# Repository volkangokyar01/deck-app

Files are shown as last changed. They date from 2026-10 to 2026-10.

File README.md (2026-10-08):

## Firmware derleme

```sh
tools/build_firmware.sh      # arduino-cli compile → firmware/bin → embed_firmware.py → build.py
```

Gerekenler: arduino-cli, esp32:esp32 3.3.12, LovyanGFX 1.2.x, ArduinoJson 7.4, NimBLE-Arduino 2.5.1. Betik Arduino'ya `BOARD_HAS_PSRAM` verir (yoksa Arduino 3.x kendi PSRAM katmanını derlemez, 8 MB ek bellek kullanılmaz) ve Arduino çekirdeğinin önbelleğini bu bayraklara göre ayırır (`firmware/VolkanDeck/build/cache-…`). Betik NimBLE'ye `MYNEWT_VAL_BLE_STORE_MAX_CCCDS=32` ve `MYNEWT_VAL_BLE_STORE_MAX_BONDS=4` verir; bunlar olmadan derleme bilerek hata verir (ayrıntı: `docs/kararlar-ve-pinler.md`, 2026-10-08). `arduino-cli` başka yerdeyse `ARDUINO_CLI=/yol/arduino-cli`, ayar dosyası için `ARDUINO_CONFIG=/yol/cli.yaml`.

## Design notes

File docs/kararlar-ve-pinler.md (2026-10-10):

# Volkan Deck — kararlar ve pinler

## Donanım
- LilyGO T-Display-S3 (ESP32-S3R8, 16MB Flash / 8MB OPI PSRAM, 1.9" 320x170 ST7789 8-bit paralel, dokunmatik DEĞİL)
- KY-040 döndürgeç, 2 × MX switch + 1u tuş kapağı (A/B; henüz alınmadı), Efcell 2000 mAh 3.7V Li-Po, 2 pin JST 1.25 mm uzatma kablosu
- Kartın arkasına pin başlıkları lehimli (Dupont ile bağlanıyor)

## Kullanım modeli: uygulama başlatıcı
- Döndürgeç listesi: [Ana sayfa] + uygulamalar. Sağa/sola: gezinir; basma: seçili uygulamayı açar (ana sayfada isteğe bağlı uygulama); uzun basma (0,7 sn): ana sayfaya dön
- A ve B butonları: atanan uygulamayı doğrudan açar (hızlı açma)
- Kartın kendi tuşları (v1.1.1'den itibaren yer değiştirdi): GPIO 0 (BOOT) = güç (kısa: ekran kapat/aç, 2 sn: derin uyku, tekrar basınca uyanır), GPIO 14 = reset (bırakınca ESP.restart; yalnız firmware çalışırken, yükleme modunda etkisiz)
- Kapanma (2026-10-05): yazılımsal güç kesici yok; kapalı durum derin uykudur, USB takılıyken kart hâlâ güç çeker. GPIO0 RTC pull-up açık / pull-down kapalı, RTC çevre birimi açık; tuş kesintisiz 80 ms bırakılmadan EXT0 (LOW) kurulmaz. Arka ışık GPIO38 ve LCD güç GPIO15 LOW tutulur; diğer uyandırma kaynakları temizlenir, BLE durdurulur, USB bağlantısı kesilir
- Kapalı durum RTC_NOINIT_ATTR içindeki 32 bit işaretle korunur: setup'ın ilk kontrolü, işaret varken POWERON ve EXT0 dışındaki reset/uyanışlarda ekranı açmadan sessizce yeniden uyutur (USB-Serial-JTAG DTR/RTS, watchdog, RTC belleği korunmuş brownout dahil). Gerçek EXT0 veya POWERON işareti temizler; GPIO0/LCD RTC hold ve RTC yapılandırması, arka ışık hold normal açılışta bırakılır. CDCOnBoot nedeniyle Arduino çekirdeği USB'yi setup'tan önce başlatır; sessiz yolda hemen bağlantısı kesilir, firmware HID/seri başlatmasına ulaşılmaz. ROM yükleme modu veya RTC belleğini kaybettiren güç düşüşü yazılımla engellenemez
- Donanım doğrulaması bekliyor: pil/USB'de uzun basma → kapalı kalma → tekrar tuşla uyanma, masaüstünün 3 sn bağlantı denemeleri, DTR/RTS resetleri, watchdog/brownout sonrası RTC işareti ve ekran/arka ışık seviyeleri; kapalı akımı ölçülmeli
- Boşta kalınca ana sayfaya dönüş (varsayılan 60 sn). Karartma ve otomatik kapanma kabloda ve pilde ayrı (v1.5.1): device.dimAfterUsb / sleepAfterUsb (varsayılan 30 sn / kapalı), device.dimAfter / sleepAfter (pilde, varsayılan 30 sn / 5 dk); 0 = kapalı. Kablo = USB'ye bağlı ya da şarj oluyor
- Ekran teması (2026-10-05): device.theme = auto (varsayılan) / dark / light. Koyu: saf siyah zemin, nötr griler; açık: kırık beyaz kasaya uygun sıcak beyaz. device.lightFrom = 420 (07:00), device.darkFrom = 1140 (19:00), yerel gece yarısından sonraki dakika; 0..1439 ile sınırlı. Eski config bu varsayılanları alır.
- Otomatik tema: açık başlangıcı dahil, koyu başlangıcı hariç; açık başlangıcı daha geçse gece yarısını aşan aralık, başlangıçlar aynıysa tüm gün koyu. Saat masaüstünün `stats.time` (epoch + tz) verisinden, arada millis ile ilerler; ilk saat gelene kadar koyu. Açılışta ve ayar değişince uygulanır, döngüde 3 sn’de bir denetlenir; değişince tam ekran çizilir (kapatma/reset yazıları da aynı palet).
- Ekran 180° çevirme: Cihaz ayarları → "Ekranı 180° çevir" (device.flip)

## Medya ve Ses/parlaklık sayfaları (v1.3.0, 2026-10-05)
- 2026-10-06 (v1.5.3): Döndürgeç ve A/B ile Spotify, Apple Music veya YouTube Music açılınca etkin Medya sayfasına geçilir; oynatıcı yalnız oturum için sabitlenir, pages.media.player değişmez. Ad ve launch.value/path/mac üzerinde büyük-küçük harf duyarsız tanıma cihazda yapılır. pages.media.launch (none / spotify / music / ytmusic, eski ayarda none) çalan uygulama yokken masaüstü uygulamasının açacağı oynatıcıdır; oturum sabiti önce gelir. Oynatıcı yokken açma seçilmişse masaüstü ctl:app bildirir; yeni masaüstü companion.mediaLaunch:true yeteneğini bildirir, böylece ilk durum yanıtından önce de sabit oynatıcıya oynat iletilir; eski masaüstünde eksik yetenek false sayılır. Mevcut evt media ve HID yolu korunur, masaüstü yokken kararı işletim sistemi verir.
- Döndürgeç listesi: [Ana sayfa] [Medya] [Ses ve parlaklık] + uygulamalar (pages.media.enabled / pages.system.enabled)
- Medya: oynatıcı çipleri (Spotify / Apple Music / YouTube Music), şarkı, sanatçı, süre çubuğu, ses. Bas: oynat/duraklat · A: önceki · B: sonraki · basılı tut: ses modu (çevir: ses, 6 sn sonra çıkar) · çift bas: oynatıcı değiştir (oto → Spotify → Apple Music → YouTube Music). Varsayılan: pages.media.player
- Medya sayfasında kalma: pages.media.stay (bool, varsayılan true; eski config'te eksikse de true). Medya ayarındaki "Medya sayfasındayken ana sayfaya dönme" açıkken yalnız Medya sayfasında home.returnAfter atlanır; karartma ve pilde otomatik kapanma aynen devam eder. Kapatılırsa normal ana sayfaya dönüş süresi uygulanır
- Ses ve parlaklık: iki satır. Bas: ayar modu ses ↔ parlaklık · çevir: değer (ses %2, parlaklık %5) · basılı tut: çık · A: sessiz · B: satır değiştir
- Masaüstü uygulaması yoksa cihaz HID tüketici tuşları gönderir (oynat/duraklat, ileri, geri, ses ±, sessiz, parlaklık ±); BLE rapor haritasına rapor 2 eklendi (Bluetooth'ta yeniden eşleştirme gerekebilir)
- Windows: win-helper.ps1 sürekli açık (SMTC medya oturumları, Core Audio, WMI + DDC/CI parlaklık; parlaklık 10 sn'de bir okunur). Tarayıcı oturumları YouTube Music sayılır
- macOS: AppleScript (Spotify, Music; Chrome/Edge/Brave/Safari'de music.youtube.com sekme adı; ses), parlaklık JXA + DisplayServices (MacBook Air'de denendi, çalışıyor). YouTube Music kontrolü medya tuşuyla
- Ekran fontlarında yalnız ASCII + Türkçe harfler var; şarkı adları uygulamada sadeleştirilir (é → e)
- Albüm kapağı (v1.3.2): macOS'te Spotify artwork URL, Music yerel artwork verisi; yoksa iTunes Search API. Windows'ta seçili Spotify/Apple Music SMTC oturumunun thumbnail'ı. Parça değişince arka planda alınır, 64×64 RGB565 olarak USB'den gönderilir; tarayıcı/YouTube Music için kapak yok

## Ana sayfa
- Sol: 128x128 animasyon alanı (hazır: fan [CPU sıcaklığıyla hızlanır], radar, nabız, ekolayzer; veya kullanıcı GIF'i → RGB565 kareler, en fazla 60, /anim.bin)
- GIF kalıcı (v1.2.1): yükleme doğrudan flash'a yazılır (/anim.tmp → /anim.bin), config'e home.anim.kind="custom" kaydedilir; açılışta PSRAM'e, olmazsa RAM'e (≤96 KB) yüklenir, o da olmazsa kareler flash'tan akıtılır
- GIF'in kendi kare süreleri (v1.3.1): kare süreleri eşit değilse (ör. hareketler arasında uzun bekleme) ayar sayfası `anim_begin` içinde `delays` (ms, kare başına) gönderir; /anim.bin başlığında bayrak bit0 = süre tablosu var (başlıktan sonra n × uint16). Süre tablosu yoksa sabit kare/sn kullanılır. Süre tablosu varken `fps` yalnız tasarruf hızını sınırlar (`ecoAnimFps = min(animFps, ecoFps)`); 2026-10-06'dan beri ayar sayfası onu ortalamadan değil en kısa kareden hesaplar, yoksa uzun beklemeler ortalamayı ~1 kare/sn'ye düşürüp tasarrufta animasyonu donduruyordu. GIF 60 kareden uzunsa kare atlanır ve süre tablosu gönderilmez
- Animasyonun altı: A/B tuşlarına atanmış uygulamaların ikonu + adı (v1.3.0'da harf yerine ikon; yeni yerleşimde üst üste iki satır olduğu için A/B harfi de yeniden gösteriliyor)
- Sağ: iki kart yuvası (v1.4.0, home.cards, varsayılan cpu + gpu; 186×76 / 186×75). Her yuvaya ayar sayfasında biri seçilir; veriyi masaüstü uygulaması USB'den `stats` ile gönderir. Cihaz Wi-Fi kullanmaz
  - CPU / GPU: büyük °C, ad (home.cpuLabel/gpuLabel boşsa bilgisayardan gelen ad), başlıkta güç W ve yük %, ikinci satırın sağında GPU fan % + VRAM (5,2/12 GB) / CPU GHz, son 40 sıcaklığın çizgisi, 0–110 °C çubuk; sarı/kırmızı eşikler (CPU 85/95, GPU 80/87). Sıcaklık gelmezse (sürücü yok, Intel Mac) büyük rakam yük % olur, sağda "sıcaklık okunamıyor"
  - Saat: ortada büyük SS:DD (24 saat), altında Türkçe tarih ("Pzt 5 Eki"); `time` (epoch + tz) gelir, arada millis ile ilerler
  - Hava durumu: şehir, durum adı, WMO kodundan vektör ikon (açık, parçalı bulutlu, bulutlu, sis, yağmur/çisenti, kar, gök gürültüsü; yalnız gündüz), büyük °, sağda en yüksek / en düşük (▲/▼), başlıkta yağış %. Şehir ayar sayfasında Open-Meteo şehir aramasıyla seçilir (home.weather {city, lat, lon}, varsayılan İstanbul); cihaz city'yi yalnız veri gelmeden önce etiket olarak kullanır
  - Döviz: USD ve EUR iki satır, TL karşılığı 2 ondalık (virgüllü), sağda önceki güne göre % değişim (yeşil ▲ / kırmızı ▼, değişim yoksa gri)
  - Ağ: büyük indirme hızı (Mb/s; 1 Mbit/s altında kB/s, 1000 üstünde Gb/s), altta yükleme, başlıkta ping (yeşil < 40 ms, sarı < 100, kırmızı), indirme çizgisi (0 tabanlı)
  - Eskime: cpu/gpu/net 5 sn, hava/döviz 2 saat; eski veya null alan "-" gösterir (uydurma değer yok). Uygulama kapalıysa kartta "Masaüstü uygulaması kapalı", açıksa "Veri bekleniyor…"
- Eski sıcaklık yolu v1.4.0'da kaldırıldı: cihazın Wi-Fi ile LibreHardwareMonitor data.json okuması (Sensors.h), sensors.* ayarları, sensor_test / temps komutları ve temps olayı. Eski config'teki sensors nesnesi yok sayılır; get_config yanıtından ve set_config kaydından silinir (Wi-Fi şifresi dahil)
- Ana sayfa veri kaynağı: masaüstü `app/stats.js` → USB `stats` (firmware ≥1.4.0). Windows NVIDIA GPU: sürücüyle gelen `nvidia-smi` sürekli CSV akışı; AMD/Intel GPU desteği henüz yok. CPU yükü `os.cpus()` farkları; desteklenmeyen alanlar `null`.

## Ekran yerleşimi (2026-10-05, "her pikseli kullan")
- Kural: dış kenar 2 px, paneller arası 2 px; paneller çizgiyle değil zemin tonuyla ayrılır (koyu SC_PANEL #0F1012 / SC_BG #000000; açık #ECE8E0 / #FAF8F3). Seçili/odaklı alan çerçeve yerine renk tonuyla gösterilir (amber karışımı)
- Üst renkli 3 px çizgi kaldırıldı; sayfa rengi artık sayfa sayacının önündeki 8 px noktada. Durum satırı y 0..13 (eskiden 0..23), içerik y 15..167
- Ana sayfa: animasyon 128×128 sol üst köşede (2,2), köşe yarıçapı 8 aynı; durum satırı animasyonun sağında (sayaç x 134). A/B satırları animasyonun altında üst üste (A üstte; harf + ikon + ad, 128×17). CPU/GPU kartları 186×76/75 (eskiden 174×62); sıcaklık 36 px
- Uygulama sayfası: ikon r 33 (eskiden 31), yan ikonlar r 21, ad tam genişlikte; A/B yuvaları 157×26, alt kenara yaslı
- Medya: çipler y 16, kapak 64×64 (2,37), başlık/sanatçı/süre çubuğu yanında; sabitlenen oynatıcı çipi çerçeve yerine kendi renginde soluk dolgu; ses kendi panelinde (86×62), % 18 px kalın; ses modunda panel amber tonlu
- Ses ve parlaklık: iki satır 316×76/75, değer 36 px, çubuk 8 px; odaklı satır amber tonlu (çerçeve yok)
- Bildirim (toast): çerçeveli siyah kutu yerine dolu amber hap, alt kenarda (y 142..167)
- 36 px font: Fonts.h `fN36`, Inter SemiBold, yalnız " %+,-./0-9:" (8,6 KB; v1.4.0'da saat ve ondalıklar için ":,." eklendi, eski glifler aynı); üretimde mevcut fontların VLW kuralları (asc = boy, glif genişliği = ilerleme) kullanıldı. Diğer yazılarda en küçük boy yine 9 px
- Simülatör (web/body.html) aynı koordinatları ve koyu/açık paletleri kullanır; otomatik tema tarayıcının yerel saatine göre 3 sn’de bir denetlenir. Cihaz ayarları → Ekran teması; otomatik seçilince iki HH:MM başlangıç alanı açılır. Sayfa/marka, oynatıcı ve kullanıcı uygulama renkleri sabit; dolgularda kontrasta göre beyaz/koyu yazı, soluk renklerde mevcut zemin/panel ile karışım. Hazır Icons.h ikonları alfa maskesi; albüm kapağı, uygulama ikon görselleri ve kullanıcı GIF kareleri değiştirilmez

## Uygulama ekleme
- "Bilgisayardan seç…" veya sürükle-bırak: .exe (PE'den ikon + ad), .lnk, .url
- Masaüstü uygulamasında dosya yolu da kaydedilir (app.targets.win); macOS'te .app seçilir veya Finder'dan sürüklenir (app.targets.mac)
- Uygulama başına "Arka planda aç" (app.bg): Windows start /MIN, macOS open -g

## Uygulama açma (karar 2026-10-05)
- Kullanıcı Windows arama veya Çalıştır (Win+R) kullanılmasını istemiyor: uygulamalar yalnızca masaüstü uygulaması tarafından sistem çağrısıyla açılır
- Masaüstü uygulaması kapalıyken cihaz yazmaz, "Volkan Deck uygulaması açık değil" gösterir; klavye yedeği (Win+R / Başlat / Spotlight) yalnızca device.kbFallback açılırsa (varsayılan kapalı)
- Görev çubuğu (Win+1..9) ve kısayol tuşu yöntemleri klavyeyle gönderilmeye devam eder
- Yöntem adları masaüstünde: "Dosya, adres veya komut" (run) ve "Uygulama adı" (search → Başlat menüsü kaydı, arama UI'si yok)

## Masaüstü uygulaması (Windows + macOS) — 2026-10-05
- Electron 44.5.1, tek kod tabanı; ayar sayfası pencere içinde (Web Serial; ana süreç VID 0x303A portunu kendisi seçer, 3 sn'de bir otomatik bağlanır)
- Cihaz → {"evt":"launch","app","name","method","value","path","mac"}; uygulama yerel ayardan targets/bg'yi tamamlar
- Windows: .exe → CreateProcess (cwd = klasörü); .lnk/.url → ShellExecute (openPath); adres → openExternal; komut → doğrudan exe ya da cmd start (App Paths); ad → Get-StartApps + shell:AppsFolder; bg → start /MIN
- macOS: open / open -a / mdfind; bg → open -g
- Kalp atışı {"cmd":"companion","os":"win|mac"} 2 sn'de bir; firmware 6 sn içinde aldıysa ve port açıksa (DTR) doğrudan açar
- Windows CPU sıcaklık/güç: PawnIO **2.2.0** + LibreHardwareMonitorLib **0.9.6** (.NET Framework paketi, MPL-2.0); eski web sunucusu kurulumu yok. LHM 0.9.5’te PawnIO’ya geçti. PawnIO sürücü DACL’si SYSTEM/yönetici erişimi gerektirdiği için uygulamada tek seferlik “CPU sıcaklığı için sürücüyü kur” adımı vardır. SHA-256 + Authenticode doğrulamasından sonra aynı UAC içinde SYSTEM sensör görevi oturum açılışına kaydedilir; Electron normal kullanıcı olarak kalır.
- Sensör görevi `%ProgramFiles%\VolkanDeckSensors\<SID>` içindeki yöneticiye ait salt okunur kod/DLL’lerle CPU paket sensörünü okur; `%ProgramData%\VolkanDeckSensors\<SID>\readings.json` kullanıcıya yalnız okuma izniyle sunulur. Ağ dinleyicisi/komut kanalı yok; beş saniyeden eski ya da hatalı değer `null`. Görev uygulama kapalıyken de çalışır; kaldırmak için yönetici PowerShell’de `Get-ScheduledTask 'VolkanDeckSensors-*' | Unregister-ScheduledTask -Confirm:$false`, ardından korumalı sensör klasörlerini silin. PawnIO ayrı olarak Windows uygulama listesinden kaldırılabilir.
- Apple Silicon macOS: MIT lisanslı **macmon 0.8.2**, `macmon pipe -i 1000` JSON akışı (sudo yok), CPU/GPU sıcaklık/yük/güç ve GHz; GPU adı Apple çip adı. İndirme arşivi SHA-256 ile sabitlenir, ikili ad-hoc imzalanıp `codesign --verify --strict` ile doğrulanır. Intel Mac veya sensör hatasında `os.cpus()` yükü, sıcaklıklar `null`.
- Ağ: aktif loopback dışı arayüzlerin byte farkları → Mbit/s; Mac `netstat -ibn`, Windows ayrı küçük PowerShell/.NET yardımcısı. Ping her 5 sn’de 1.1.1.1:443 TCP bağlantı süresi (yedek 8.8.8.8).
- Hava: [Open-Meteo](https://open-meteo.com/en/docs) güncel °C/WMO kodu ve bugünün max/min/yağış olasılığı, `home.weather.lat/lon` seçilince, 15 dk önbellek. Kur: [Frankfurter v2](https://frankfurter.dev/) ECB verisi, USD/TRY + EUR/TRY ve önceki yayımlanan iş gününe göre %, 30 dk önbellek. Anahtar gerekmez; Electron `net.fetch`, 10 sn timeout, hatada son iyi veri (2 saate kadar).
- İkili/DLL dosyaları ilk kullanımda kullanıcı veri klasörüne sabit SHA-256 ile indirilir; repo ve GitHub `app/` güncellemesi küçük kalır. Kaynaklar, hash’ler, bağımlılıklar ve doğrulama notları: `app/vendor/README.md`. CPU/GPU/net yaklaşık 1 sn, saat bağlantıda + 60 sn; yavaş gruplar ayrıca ilk yanıt geldiğinde gönderilir. Medya/sys/kapak akışından bağımsızdır.
- Çarpıya basınca kapanmaz, arka planda çalışır: Windows'ta sistem tepsisi simgesi (+ görev çubuğu durumu), macOS'te yalnız menü çubuğu simgesi (Dock'ta görünmez; accessory modu). Simge bağlantı durumunu gösterir (dolu / yarım / boş)
- İlk açılışta "bilgisayar açılınca başlat" açık
- Dağıtım: VolkanDeck-kurulum.zip (Windows-Kur.bat / Mac-Kur.command Electron'u GitHub'dan indirip kurar). Mac'te /Applications/Volkan Deck.app kurulu; güncellemeler Contents/Resources/app'e yazılıyor
- macOS 27'de app.getFileIcon ana süreçte çöküyordu; ikon artık plutil + sips ile .icns'ten okunuyor
- Kaynak: GitHub volkangokyar01/deck-app (app/main.js, preload.js, companion.js — ayar sayfasının IIFE'sine gömülür, tools/build.py)
- Sınır: doğrudan açma USB'de; v1.6.0'dan itibaren kablo bu bilgisayara takılı değilse Bluetooth veri kanalıyla da (aşağıda)

## Bluetooth veri kanalı (v1.6.0, 2026-10-06)
- Önceden Bluetooth yalnız HID klavye + medya tuşuydu; ayarlar, stats, medya ve launch olayları yalnız USB seri porttan gidiyordu
- Yeni GATT servisi 7d9a0001-5c2e-4b7a-9f3d-1a6c0de5d001: RX 7d9a0002 (write / write without response, şifreli bağlantı ister), TX 7d9a0003 (notify). İçerik USB ile aynı satır başına bir JSON
- Yanıt komutun geldiği yola gider; olaylar (launch, media, sys, input, select, status) USB'deki masaüstü uygulamasına, yoksa Bluetooth'takine
- İki bilgisayar aynı anda (biri USB, biri Bluetooth): ekranı USB'deki besler; Bluetooth'tan gelen stats / media / media_art / sys yok sayılır
- Cihaz bağlıyken de yayın yapar (en fazla 2 bağlantıya kadar), Windows'ta Web Bluetooth taraması bağlı cihazı bulabilsin diye. Yayın: görünüm 0x03C1 + HID ve Volkan Deck servis UUID'leri; ad tarama yanıtında
- hello yanıtında via ("usb" / "ble") ve Bluetooth'ta mtu; uygulama yazmaları mtu-3'e (en çok 240) böler, hello'dan önce 20 bayt
- Masaüstü uygulaması: önce USB; kablo yoksa 12 sn'de bir Web Bluetooth ile servis UUID'si üzerinden arar (ana süreç seçiciyi kendisi kapatır, 8 sn'de bulamazsa vazgeçer). Kablo takılınca USB'ye geçer. Bağlantı ayarı "Sadece USB" ise Bluetooth denenmez
- Bluetooth'ta yapılmayanlar: firmware yükleme (dfu → usb_only), animasyon yükleme (uygulama engeller)
- macOS: Electron'un Info.plist'inde NSBluetoothAlwaysUsageDescription var; Mac-Kur.command Türkçe açıklama yazar

## Firmware (v1.15.1)
- Arduino-ESP32 3.3.12, kart lilygo_t_display_s3, USB-OTG (TinyUSB) + CDC on boot, özel partitions.csv (4 MB app0 + 12 MB LittleFS)
- Kütüphaneler: LovyanGFX 1.2.x, ArduinoJson 7.4, NimBLE-Arduino 2.5.1
- Yükleme: ayar uygulamasında "Firmware yükle" (esptool-js 0.7.0, bin'ler HTML'e gömülü)
- Yükleme sonrası yeniden başlatma (2026-10-05): dfu komutu kalıcı "zorla indirme" bayrağı (RTC_CNTL_OPTION1) bırakıyordu ve esptool-js RTS ile sıfırlamıyordu → kart yükleme modunda kalıyordu. Artık bayrak temizlenip RTC watchdog ile yeniden başlatılıyor, yedek olarak RTS darbesi
- v1.0.1 / 1.0.2: USB seri okuma ayrı görevde; PSRAM yedeği; status olayında rx / satır / psram
- v1.1.0: companion / temps komutları, launch olayı, launch.path / launch.mac, device.host (win/mac)
- v1.1.1: güç ve reset tuşları yer değiştirdi (güç GPIO 0 / BOOT, reset GPIO 14)
- v1.2.0: device.kbFallback (varsayılan kapalı) — masaüstü uygulaması yoksa Win+R / arama / Spotlight yazılmaz
- v1.2.1: ana sayfa GIF'i kalıcı (flash'a akışla yazma, açılışta yükleme)
- v1.3.0: Medya ve Ses/parlaklık sayfaları, HID tüketici tuşları, ana sayfada A/B ikonları, CPU/GPU başlıkları
- v1.3.1: ana sayfa GIF'i kare başına süreleri korur
- v1.3.2: medya sayfasında albüm kapağı
- v1.4.0: ana sayfada iki kart yuvası (cpu, gpu, clock, weather, fx, net) ve `stats` komutu; Wi-Fi / LibreHardwareMonitor yolu, sensor_test, temps kaldırıldı (Wi-Fi kitaplığı çıkınca program ~1,6 MB → ~0,96 MB). Yerleşim yenilemesi ve albüm kapağı da bu sürümde
- v1.4.1: döndürgeç yön değiştirince ilk tık kaybolmuyor (açılışta gerçek pin durumu, her tık yuvasında sayaç sıfırlanır)
- Gözlem (2026-10-02): v1.0.0 kartta komutlara yanıt vermedi (RX). Sonraki sürümlerin kartta doğrulanması bekleniyor

## Kasa v4 (güncel) — case/v4
- Elgato Stream Deck Mini tarzı kompakt kama: bütün kontroller tek eğimli yüzde (55°); ekran üstte, altında A (x −33) / B (x −11) MX ve döndürgeç (x +27, düğme Ø30 × 18); kartın tuşları ekranın solunda
- 100 × 85 × 68 mm; ön görünüş köşeleri R10, yüz kenarı 45° pah, ekran çevresinde ince çizgi oluk, pahlı pencere
- Arka düz gömme kapak (76 × 37), 4 kanca; pil tabanda köpük bantla (62 × 37 × 14 alan)
- Pin alanı: PCB arkasından 25 mm boş; klipsler yalnız kart uçlarında
- USB-C sol duvar, 14 × 9 delik (tepesi 45° sivri) + ~13 mm kanal
- Bambu Studio (2026-10-02): 0.12mm High Quality @BBL P2S, PLA Basic, dokulu PEI; dikiş "Arka", gövde 180° çevrili; 4 sa 45 dk, 82,9 g
- Kaynak case/v4/deck_case4.py

## Eski kasalar
- v3: tek gövde kama, 5° tuş güvertesi + 60° ekran; 126 × 114 × 70
- v2: açılımlı taban + A çerçeve kule; estetik bulunmadı, kancalar pinlerle çakışıyordu
- v1.1: 74,5 × 80 × 60 mm, ekran 60°
- v1.5.1: karartma ve otomatik kapanma kabloda / pilde ayrı ayarlanır, ikisi de kapatılabilir (dimAfterUsb, sleepAfterUsb; eski config'te kablo = eski karartma süresi, kapanma yok)
- v1.5.2: Ses ve parlaklık sayfasında mikrofon satırı, B tuşu varsayılan mikrofonu kapatır / açar (sys.micMute / evt sys micMute; Windows Core Audio capture mute, macOS giriş seviyesi 0 ↔ önceki seviye). Yeni "Widgetlar" sayfası (pages.widgets.enabled / cards, 1–4 kart; yerleşim 1: tam, 2: alt alta, 3: üst geniş + alt iki, 4: 2×2), döndürgeçte ana sayfadan hemen sonra, boşta ana sayfaya dönmez
- v1.6.0: Bluetooth veri kanalı (masaüstü uygulaması kablosuz da bağlanır)
- v1.6.1: Bluetooth gönderimi ayrı görevde (kuyruk 24); BLE alma geri çağrısı kuyrukta beklemez. 1.6.0'da ana döngü notify için bekliyor, NimBLE görevi de kuyrukta beklediği için menüler yavaşlıyor, stats/sys satırları düşüyordu
- v1.6.2: firmware sürümü değişince eşleşmiş bilgisayarlara GATT "service changed" bildirimi (NVS vdble/fw); macOS eski servis listesini önbellekte tutuyordu. Uygulama Bluetooth'u USB'den önce dener (requestDevice taze kullanıcı etkinliği ister) ve hataları günlüğe yazar

## Pinler
| Parça | Pin | GPIO |
|---|---|---|
| KY-040 | CLK / DT / SW | 1 / 2 / 10 |
| KY-040 | + | 3V3 (5V değil) |
| Buton A / B | → GND | 11 / 12 |
| Güç tuşu (kart, BOOT) — v1.1.1+ | | 0 |
| Reset tuşu (kart) — v1.1.1+ | | 14 |
| LCD güç (pilde) | | 15 HIGH |
| LCD arka ışık (PWM; uykuda LOW) | | 38 |
| Pil ölçümü | | 4 (×2 bölücü) |

## Seri protokol
115200 baud, satır başına bir JSON. Komutlar: hello, get_config, set_config, launch, companion, stats (v1.4.0+, yanıt yok; gruplar isteğe bağlı, alanlar null olabilir: cpu {name, temp, load, power, clock}, gpu {+ fan, vram, vramTotal}, net {down, up Mbit/s, ping ms}, weather {city, temp, code WMO, hi, lo, rain}, fx {usd, eur, usdChg, eurChg}, time {epoch UTC sn, tz sn}), media (player, name, title, artist, playing, pos, dur, ctl app|keys, artKey), media_art (key, w=64, h=64, data=base64 RGB565 little-endian; boş key kapağı temizler), sys (vol, mute, bright), anim_begin, anim_data, anim_end, icon_set, dfu, restart. Olaylar: evt=input, select (home/media/system/uygulama id), launch, media (action play_pause|next|prev|select, player), sys (vol | bright | mute), status (fw, rx, lines, psram).

## 2026-10-06 — Boşta tasarruf (firmware 1.6.3)

Kabloda `device.ecoAfterUsb=60`, pilde `device.ecoAfter=30` saniye; 0 kapalı, sınır 3600. Karartma/kapanmadan bağımsızdır. Masaüstü verisi kullanıcı girdisi sayılmaz. `device.dimLevelUsb` / `device.dimLevel`: normal parlaklığın %5–90’ı, varsayılan %17; karartılmış parlaklık en az %5, güç kaynağı değişince yeniden uygulanır (2026-10-06). `device.ecoFpsUsb` / `device.ecoFps`: 0–15 kare/sn (seçenekler 15, 10, 8, 4, 2, 1, Durdur; firmware 1.7.1 öncesi en çok 8), varsayılan 4; 0 son tamamlanan kareyi dondurur ve animasyon alanı yeniden çizilmez (2026-10-06). Eski ayarlarda da bu varsayılanlar geçerlidir. Boşta ana sayfa animasyonu seçilen hızla sınırlı ve yalnız kendi bölgesinde; periyodik tam ekran çizimi durur, saat dakika sınırında güncellenir. Encoder, A/B ve kısa güç girdisi önce CPU'yu 240 MHz'e döndürür; ilk eylem yutulmaz. Aktarım, ayarlama ve bildirim tasarrufu engeller. Döngü beklemesi 2 ms; light sleep yok.

ESP32-S3 için 80/240 MHz aynı 480 MHz PLL'den bölünür ve APB 80 MHz kalır ([IDF saat kodu](https://github.com/espressif/esp-idf/blob/v5.5.4/components/esp_hw_support/port/esp32s3/rtc_clk.c)). Arduino 3.3.12 saat değişimi FreeRTOS tick bölücüsünü günceller ([CPU HAL](https://github.com/espressif/arduino-esp32/blob/3.3.12/cores/esp32/esp32-hal-cpu.c)); S3 UART varsayılanı XTAL'dir ([UART HAL](https://github.com/espressif/arduino-esp32/blob/3.3.12/cores/esp32/esp32-hal-uart.c)). Bu cihazda `Serial` TinyUSB CDC'dir, UART baud ayarı gerekmez. PLL kapatılmadığından USB saatinin korunması beklenir; BLE için 80 MHz altına inilmez. Donanımda süreklilik henüz doğrulanmadığı için CPU geçişi varsayılanı açık `VOLKAN_ECO_CPU` bayrağıyla kapatılabilir. Sıcaklık ve ilk girdi gecikmesi README kontrol listesinde gerçek cihazla ölçülecek.

## 2026-10-06 — Tema başına animasyon (firmware 1.7.0)

"Kendi GIF'im" için iki yuva: koyu tema `/anim.bin`, açık tema `/anim_light.bin`. Cihaz temayı saate göre kendisi değiştirdiği için iki dosya da kartta saklanır ve çizim anında `themeAnim(lightTheme)` seçer; bir yuva boşsa iki temada diğeri oynar. `anim_begin` isteğe bağlı `"slot":"light"` alır (yoksa koyu), `anim_clear` bir yuvayı siler, `hello` yanıtında `anim` / `animLight` kare sayıları var. Koyu yuva hız ayarını (`home.anim.fps`) izler, açık yuva dosyadaki hızı ya da GIF'in kendi kare sürelerini kullanır. Eski firmware `slot`'u bilmediği ve koyu animasyonun üstüne yazacağı için ayar sayfası açık tema animasyonunu yalnız 1.7.0+ karta gönderir. Bellek: iki animasyon PSRAM'e sığar (en çok 2 × 60 × 32 KB); PSRAM yoksa her yuva kendi dosyasından kare kare okunur.

## 2026-10-06 — Outlook yeni posta bildirimi (firmware 1.8.0)

Masaüstü uygulaması Outlook'u izler; okunmamış sayısı artınca cihaza `{"cmd":"mail","subject":"…","unread":5,"new":1,"ms":10000}` gönderir. Cihaz tüm ekranı kaplayan bir bildirim gösterir ve bildirim `ms` kadar (en çok 120 sn) kalır. Bildirim açıkken A, B ve döndürgece basmak `{"evt":"mail","action":"open"}` gönderir, masaüstü uygulaması Outlook'u öne getirir. Çevirmek ya da uzun basmak bildirimi kapatır. Güç ve yeniden başlatma tuşları her zamanki gibi çalışır. `"ms":0` bildirimi kaldırır.

- Bildirim ekranı karartmadan ve tasarruftan çıkarır, ama kullanıcı girdisi sayılmaz: boşta sayaçları arkada işler, bildirim bitince ekran yine kararır. Bildirim sürerken karartma, tasarruf ve kapanma beklemeye alınır. Güç tuşuyla kapatılmış ekran açılmaz.
- İki bilgisayar aynı anda bağlıysa Bluetooth'tan gelen `mail` yok sayılır (ekranı USB'deki bilgisayar besler).
- macOS: Outlook'un Dock rozetindeki okunmamış sayısı `lsappinfo` ile 3 sn'de bir okunur. İzin gerekmez; klasik ve yeni Outlook'ta çalışır. Konu okunamaz, çünkü yeni Mac Outlook'ta AppleScript yok (Microsoft Ağustos 2026'da iptal etti). Outlook'ta Dock rozeti kapalıysa bildirim gelmez.
- Windows: ayrı bir PowerShell yardımcısı (`app/win-mail.ps1`) çalışan klasik Outlook'a COM ile bağlanır (Outlook'u hiçbir zaman kendisi başlatmaz). 3 sn'de bir tüm hesapların Gelen Kutusu okunmamış sayısını okur; konu yalnız sayı artınca, en yeni okunmamış postadan alınır. Yalnız `Subject`, `ReceivedTime`, `UnRead`, `UnReadItemCount` okunur; bunlar Outlook güvenlik uyarısı açmaz. Yeni Outlook (olk.exe) başka uygulamalara posta bilgisi vermez; desteklenmez, ayarlarda belirtilir. Outlook'u açmak: App Paths'te OUTLOOK.EXE varsa `outlook.exe /recycle` (açık pencereyi öne getirir), yoksa Başlat menüsündeki Outlook.
- İzleme yalnız özellik açıkken ve 1.8.0+ bir kart doğrudan açma modunda bağlıyken çalışır. Outlook açıldıktan sonraki ilk 20 sn eşitleme sayılır, bildirim verilmez. Bağlantı yokken gelen posta sonradan gösterilmez.
- Ayarlar masaüstü uygulamasında (`state.json` → `mail`: `enabled`, `seconds` 5/10/15/30/60, `subject`), cihaz ayarına girmez. Konu `devText` ile cihaz fontlarına indirgenir (en çok 90 karakter), cihazda iki satıra kelime sınırından bölünür.

## 2026-10-06 — "Cihaza yaz" kartı yeniden başlatıyordu (firmware 1.8.1)

Windows'ta ayar yazınca kart yeniden başlıyor, ayar kaydedilmiyordu. Kart boşta tasarruftayken (80 MHz) gelen `set_config` önce `ecoSuspend()` ile CPU'yu 240 MHz'e çeviriyor, hemen ardından LittleFS'e yazıyordu; CPU geçişi donanımda doğrulanmamıştı. `VOLKAN_ECO_CPU` varsayılanı 0: tasarrufta çizim azaltma sürer, CPU frekansı değişmez.

Aynı sürümde:
- Bluetooth'ta her bağlantının kendi alma tamponu var; yanıt komutun geldiği bağlantıya, olaylar masaüstü uygulamasının bağlantısına (son `companion`) gider. Önceden iki bilgisayar (ör. Mac Bluetooth'ta, Windows yazarken) aynı tampona yazınca satırlar karışabiliyordu.
- Kırıntı: RTC_NOINIT'te son komut / aşama (`cmd:<ad>`, `apply`, `input`, `render`). Panik / watchdog / brownout sonrası `hello` yanıtında `crash` ("panic @ cmd:set_config" gibi) ve her zaman `reset`; uygulama günlüğe yazar ve bildirir.
- Uygulama her zaman önce USB'yi dener; `getPorts()` boşsa ana sürecin seçicisiz `requestPort` yanıtıyla kabloyu algılar. Bluetooth yalnız kablo yokken.

## 2026-10-06 — Bellek: "Cihaza yaz" panik veriyordu (firmware 1.8.2)

1.8.1'in kırıntısı Windows'ta `crash: "panic @ cmd:set_config"` gösterdi; aynı kayıtta `psram: 0`. Kartta PSRAM başlamıyor (qio_opi yapılandırması, `CONFIG_SPIRAM_IGNORE_NOTFOUND`), her şey ~320 KB iç RAM'de: 108 KB ekran sprite'ı, NimBLE, uygulama ikonları (uygulama başına 3,2 KB), kalıcı 24 KB seri tampon, 1.6.0'dan beri Bluetooth bağlantısı başına 24 KB tampon, 16 KB sabit dizi. `set_config` sırasında yeni `Settings` kurulurken eski ikonlar hâlâ bellekteydi ve `S = N` kopyası ikinci bir vektör ayırıyordu; vektör ayırması başarısız olunca firmware abort ediyordu.

Değişiklikler: `applyConfig` ikonları en başta bırakır ve `S = std::move(N)` kullanır; seri ve Bluetooth satır tamponları 1 KB'tan başlayıp yalnız uzun satırda büyür, satır bitince küçülür ve kuyruğa kopyalanmadan devredilir; Bluetooth bağlantısı kopunca tamponu serbest kalır; `anim_data` için 8 KB yalnız yükleme sırasında ayrılır, kapak doğrudan kapak tamponuna çözülür. Global RAM 90,8 KB → 74,4 KB. `status` ve `hello` artık `heap` / `block` (KB) bildirir; `set_config` kırıntısı aşama gösterir (save / apply / prune / reply). PSRAM'in neden başlamadığı donanımda ayrıca incelenmeli.

## 2026-10-06 — Komut dosyaları

Uygulama listesine komut dosyası eklenebilir; çalıştırmayı masaüstü uygulaması yapar (cihaz yalnız launch olayı gönderir). Windows: `.ps1` → `powershell -NoProfile -ExecutionPolicy Bypass -File` ("Arka planda aç" ile gizli pencere), `.bat` / `.cmd` → `cmd start` (klasörü çalışma dizini), `.vbs` → `wscript`. macOS: `.sh` / `.bash` → bash, `.zsh` → zsh, `.py` → `/usr/bin/python3`, `.scpt` / `.applescript` → osascript, hepsi Terminal açmadan; `.command` Finder gibi Terminal'de açılır. Klavye yedeğinde Windows komut dosyası Çalıştır kutusuna tam yolla yazılır.

## 2026-10-07 — Pil seviyesi kablodayken de gerçek (firmware 1.8.3)
- Sorun: kabloda şarj devresi pil ucundaki gerilimi yükseltiyor (şarj akımı × iç direnç, sonra 4,2 V sabit), ölçüm >4,25 V olunca seviye doğrudan %100 yazılıyordu.
- Pilde: filtrelenmiş gerilim doğrusal değil Li-Po deşarj eğrisiyle yüzdeye çevrilir (3,30 V = %0, 4,16 V = %100); düşüşler yumuşak izlenir, kablo çıkınca 3 dk gevşeme süresince seviye yükselmez.
- Kabloda: seviye takılmadan önceki değerden başlar, şarj hızıyla artar (BAT_CHARGE_MA 500 mA / BAT_MAH 2000 mAh ≈ %25/saat, %80 üstünde yavaşlar). Üst sınır ölçülen gerilimin eğrideki karşılığı, alt sınır 0,10 V (BAT_IR_V) düşülmüş karşılığı (yalnız 4,12 V altında). %100'e varınca "şarj" biter.
- Kablo = USB host bağlı ya da gerilim >4,22 V (duvar şarjı). Seviye RTC belleğinde tutulur; güncelleme/yeniden başlatma sonrası sıfırdan tahmin edilmez. Soğuk açılış kabloda ise ilk değer gerilimden tahmin edilir.
- Durum çubuğunda "şarj" yazısı yerine yüzde + pil simgesinde şimşek.
- Şarj akımı: kartta TP4065 doğrusal şarj entegresi, programlama direnci R13 = 2 kΩ → 1000 V / 2 kΩ ≈ 500 mA (LilyGO wiki: varsayılan 500 mA; GitHub T-Display-S3 #230: en kötü durumda ≈ 520 mA). Kartta akım sensörü yok; firmware akımı ölçemez, yalnız pil gerilimini (GPIO4, ×2 bölücü) görür. Gerçek akım ısınmayla (doğrusal entegre, ~0,6 W) ve kart yükünden dolayı biraz düşük olabilir; USB-C ölçerle ya da pil kablosuna seri multimetreyle doğrulanmalı.

## 2026-10-07 — Kablo çıkınca "şarj" kalıyordu (firmware 1.8.4)
- Kartta VBUS algılama hattı yok: kablo bilgisayardan çekilince TinyUSB yalnız "suspend" verir, "mounted" bayrağı açık kalır. 1.8.3 bunu kablo sayıyordu.
- Artık kablo = USB host bağlı ve uykuda değil, ya da şarj cihazı. Şarj cihazı gerilim sıçramasından bulunur: hızlı ortalama yavaş ortalamanın 0,06 V (BAT_STEP_V) üstüne çıkınca takıldı, altına inince çekildi sayılır; USB suspend de şarj cihazı bayrağını siler. Açılışta gerilim >4,25 V ise şarj cihazıyla açıldı sayılır.
- Bilinen sınır: bilgisayar uykudayken (USB suspend) kablo takılı olsa da "şarj" görünmez, seviye pil hesabıyla devam eder.

## 2026-10-07 — Windows'ta "Cihazınızı yeniden bağlamayı deneyin" (firmware 1.8.5)
- Belirti: Windows'ta Bluetooth ayarları sürekli "yeniden bağlamayı deneyin" uyarısı veriyordu; cihaz yalnız Mac mini ile eşleşmişti.
- Neden (büyük olasılıkla): kablo Windows'a takılı değilken masaüstü uygulaması 12 sn'de bir Web Bluetooth ile cihaza bağlanıyordu. Cihaz Windows'la eşleşmemişken her bağlantı Windows'un kendi eşleştirmesini başlatıyor, bağlantı kapanınca eşleştirme yarıda kalıyor ve uyarı tekrar tekrar çıkıyordu; Ayarlar'dan elle eşleştirme de bu denemelerle çakışıyordu.
- Uygulama: Windows'ta Bluetooth ancak cihaz Windows'ta eşleşmiş görünüyorsa (Get-PnpDevice, sınıf Bluetooth, BTHLE\DEV_*, ad = cihaz adı; 60 sn önbellek) denenir; değilse kayda bir kez "Windows Ayarlar → Bluetooth ve cihazlar → Cihaz ekle" notu düşer. Başarısız denemelerden sonra bekleme 12 sn → 30 sn → 1 dk → 5 dk. Windows sorgulanamazsa engellenmez. macOS'ta değişiklik yok.
- Firmware: `{"cmd":"ble_forget"}` bütün Bluetooth eşleşmelerini siler, bağlı bilgisayarları düşürür (yalnız USB'den). hello yanıtında `bonds` (eşleşme sayısı). Ayar sayfasında Cihaz kartında "Bluetooth eşleşmelerini sil" düğmesi (USB'de, 1.8.5+).
- NimBLE en fazla 3 eşleşme tutar (CONFIG_BT_NIMBLE_MAX_BONDS 3); dördüncü bilgisayar en eskisini siler.

## 2026-10-07 — Bağlantılar sayfası: Bluetooth bilgisayarı cihazdan seçilir (firmware 1.9.0)
- Kullanıcı isteği: eşleştirme ve bilgisayar seçimi cihazdan, elle yapılsın; Bluetooth ve Wi-Fi aynı sayfada olsun (ayrı ekran yok).
- Döndürgeç listesinde yeni sayfa "Bağlantılar" (pages.connections.enabled, varsayılan açık; Ses ve parlaklık'tan sonra). Üstte Bluetooth durumu, ortada liste, altta Wi-Fi satırı.
- Liste: "Otomatik · eşleşmiş hepsi", eşleşmiş her bilgisayar (ad + "bağlı"), "Yeni cihaz eşleştir", "Eşleşmeleri sil". Bas → seçim modu, çevir → satır, bas → uygula; basılı tut veya 20 sn → çık. A: Bluetooth aç / kapat (NVS vdbt/off). B: hızlı uygulama.
- Eşleştirme yalnız eşleştirme modunda (90 sn): açılışta NimBLE bonding kapalı, modda açılır. Mod dışında eşleşmeye çalışan bilgisayar düşürülür ve cihazda "Eşleştirme kapalı" yazar. Yeni bilgisayar eşleşince mod kapanır; bir bilgisayar seçiliyse seçim yenisine geçer.
- Bilgisayar seçilince (NVS vdbt/sel, kimlik adresi) diğer bağlantılar düşürülür; diğer eşleşmiş bilgisayarlar bağlanınca şifreleme biter bitmez (kimlik adresi o an belli) düşürülür. Yayın sürer (Windows Web Bluetooth taraması için).
- Bilgisayar adı: masaüstü uygulaması Bluetooth'ta ilk companion mesajında `host` gönderir (Mac: ComputerName, Windows: COMPUTERNAME); yoksa cihaz kendi görevinde bilgisayarın GATT Device Name (0x1800/0x2A00) değerini okur; o da yoksa "Bilgisayar XXXX". NVS vdbt/n<adres>.
- Wi-Fi satırı yalnız yer tutucu ("Kapalı · yakında"): cihaz Wi-Fi kullanmıyor (PSRAM yok, ~50–70 KB RAM gerekir). Wi-Fi gelirse ağ adı ve şifre masaüstü uygulamasından USB ile gönderilecek (kullanıcı tercihi).
- hello: `btOff`.

## 2026-10-07 — Aktif bilgisayar: cihaz en son kullanılan bilgisayarı izler (firmware 1.9.1)
- Kullanıcı isteği: bilgisayarlar arası geçiş için eşleşme kaldırılmasın, hangi bilgisayar kullanılıyorsa cihaz ona gitsin.
- Masaüstü uygulaması her companion mesajında `idle` (Electron powerMonitor.getSystemIdleTime, saniye) gönderir; ilk (ack) mesajda `host` (bilgisayar adı) USB'de de gider.
- Cihaz bilgisayar başına (USB = 0xFFFE, Bluetooth = bağlantı tutamacı) son mesaj ve son kullanıcı girişi zamanını tutar; 6 sn mesaj gelmeyen, USB'si askıda olan ya da Bluetooth'u kopan düşer. En son girişi olan "aktif"tir.
- Aktif bilgisayara giden: HID tuşları ve medya tuşları (Bluetooth'ta yalnız o bağlantıya notify; önceden iki bilgisayar bağlıysa tuşlar ikisine birden gidiyordu), olaylar (launch, media, sys, input, select, status). Ekran verisi (stats, media, media_art, sys, mail) yalnız aktiften alınır; idle bildiren uygulama yoksa eski kural (USB'deki besler).
- Uygulama yoksa: tuşlar USB'ye, USB yoksa en son bağlanan Bluetooth bilgisayarına.
- Aktif değişince cihaz "Aktif: <ad>" gösterir, medya/ses verisini sıfırlayıp yeni bilgisayara status/select/media select gönderir. Bağlantılar başlığında "Aktif: <ad>", listede aktif bilgisayarın yanında "aktif"; ilk satır "Aktif bilgisayar · otomatik".

## 2026-10-08 — Asıl neden: ikinci bilgisayar eşleşince ilki siliniyordu (firmware 1.9.2)
- Windows sürekli "Cihazınızı yeniden bağlamayı deneyin" diyordu. Neden NimBLE'nin bağ deposu: Arduino-ESP32 3.3.12 sdkconfig'i CONFIG_BT_NIMBLE_MAX_CCCDS 8 ve MAX_BONDS 3 veriyor. Eşleşmiş her bilgisayar ~5 bildirim aboneliği (CCCD) saklar: HID rapor 1, rapor 2 (medya), pil, GATT service changed, Volkan Deck TX. İki bilgisayar 10 kayıt ister.
- Depo dolunca NimBLE'nin varsayılan store_status_cb'si (ble_store_util_status_rr) CCCD taşmasında "şimdiki hariç en eski eşi" eşleşmeden çıkarır. Windows eşleşip abone olurken Mac mini'nin bağı siliniyor, Mac yeniden eşleşince Windows'unki gidiyordu; Windows eski anahtarla bağlanamayınca uyarıyı veriyordu.
- Düzeltme: derlemede -DMYNEWT_VAL_BLE_STORE_MAX_CCCDS=32 -DMYNEWT_VAL_BLE_STORE_MAX_BONDS=4 (NimBLE'nin esp_nimble_cfg.h'si bu değerleri #ifndef ile alır; sdkconfig'e dokunmak gerekmez). Derlenmiş ELF'te ble_store_config_cccds 512 bayt (32 × 16), peer_secs 352 bayt (4 × 88). `tools/build_firmware.sh` bayrakları verir; Hid.h bayraksız derlemede #error verir.
- Ek güvenlik: kendi onStoreStatus'umuz CCCD taşmasında başka bilgisayarı silmez, yalnız o kaydı saklamaz (BLE_HS_ESTORE_CAP). Bağ taşması (5. bilgisayar) en eskiyi silmeye devam eder.
- Güncellemeden sonra cihazdaki ve bilgisayarlardaki eski eşleşmeler bir kez temizlenip yeniden eşleştirilmeli (eski sürümde biri zaten silinmiş olabilir).

## 2026-10-08 — "Eşleşmeleri sil" eşleşmeleri silmiyordu (firmware 1.9.3)
- NimBLE ble_gap_unpair: eş kimlik anahtarı (IRK) dağıtmışsa ve yayın ya da tarama sürüyorsa BLE_HS_EBUSY döner, hiçbir şey silmez. Mac ve Windows her zaman IRK gönderir; cihaz da hep yayında olduğu için deleteAllBonds ilk eşte başarısız oluyordu.
- bleForget artık: eşleştirme modunu kapatır, bt.hold ile yayını kilitler (bağlantı geri çağrıları yeniden başlatamaz, gelen bağlantı düşürülür), bağlantıları kapatıp en çok 1,5 sn bekler, deleteAllBonds çalıştırır; eşleşme kalırsa ble_store_clear ile depoyu tamamen siler. Sonucu döndürür: cihaz "Eşleşmeler silindi" ya da "Silinemedi" gösterir, ble_forget komutu ok / "busy" yanıtlar.

## 2026-10-08 — Menü: sayfalar döndürgeç listesinden çıktı; web sitesi kısayolu (firmware 1.9.4)
- Kullanıcı isteği: uygulamalara ulaşmak için fazla adım vardı; Medya, Ses ve parlaklık ve Bağlantılar yalnız seçilince açılan sayfalar olsun.
- Döndürgeç listesi: Ana sayfa, Kartlar, uygulamalar, en sonda "Menü" (en az bir sayfa açıksa). Liste başa sardığı için Menü ana sayfadan bir tık geride.
- Menü ekranı açık sayfaları listeler; her biri bir tuşla açılır: 3 sayfa → A / bas / B, 2 → A / B, 1 → bas. Eşleşmeyen A / B hızlı uygulamasını açar.
- Açılan sayfa (subPage) eskisi gibi çalışır (curKind sayfanın türünü döndürür); çevirince listede komşuya geçilir ve sayfa kapanır; basılı tutma, sayfanın kendi işi yoksa Menü listesine döner (Medya'da basılı tutma ses modu olarak kaldı). Müzik uygulaması açılınca Medya yine kendiliğinden açılır. select olayı açık sayfanın kimliğini (media / system / connections) gönderir.
- Ayar sayfası: Menü önizlemesi ve düzenleyicisi; sayfa düzenleyicilerinde "Menüde göster".
- Uygulama listesinde "Web sitesi ekle": adres (https'siz de yazılabilir; yalnız http/https kabul edilir) ve isteğe bağlı ad. Uygulama "Çalıştır" yöntemiyle adresi açar (masaüstü uygulaması varsayılan tarayıcıda; yoksa Win+R). Ad alan adından gelir; ikon Google favicon hizmetinden, internet yoksa küre.

## 2026-10-08 — Menü seçimi döndürgeçle; Menü yalnız ana sayfadan sola (firmware 1.9.5)
- A / bas / B kısayolları kaldırıldı (sayfa eklendikçe ölçeklenmiyordu). Menü'de bas → imleç (son açılan sayfada), çevir → seç, bas → aç; basılı tut ya da 15 sn → seçimden çık. Liste kaydırılır (3 satır görünür), ileride eklenen sayfalar sığar. A / B Menü'de de hızlı uygulamalarını açar.
- Açık sayfadan basılı tutunca (sayfanın kendi işi yoksa) Menü listesine imleç o sayfadayken dönülür.
- Döndürgeç adımı (wheelStep): Menü listenin sonunda durur ama yalnız ilk öğede (ana sayfa) sola çevirince gelir. Son uygulamadan sağa → ana sayfa (sarma kapalıysa durur); Menü'den sağa → ana sayfa, sola → son uygulama. Ayar sayfası önizlemesi aynı kuralı kullanır.

## 2026-10-08 — A / B'ye Menü sayfaları atanabilir (firmware 1.9.6)
- quick.a / quick.b bir uygulama kimliği ya da "__media", "__system", "__connections" olabilir. Cihaz sayfa kimliğinde Menü'deki sayfayı doğrudan açar (sayfa kapalıysa "… ekranı kapalı"). Ana sayfada ve uygulama görünümünde A / B satırı sayfanın simgesini ve adını gösterir.
- Sayfaların kendi A / B işi sürer: Medya'da önceki / sonraki, Ses ve parlaklık'ta sessiz / mikrofon, Bağlantılar'da A Bluetooth aç / kapat.
- Ayar sayfası: Buton A / B düzenleyicisinde önce üç ekran, sonra uygulamalar; cihaza giden yapılandırma ve fark listesi sayfa kimliklerini korur.
- Ayar sayfasının bütün betiklerini derleyen test eklendi (page-syntax.test.js): fazladan bir parantez sayfayı açılışta bozmuştu, işlev testleri yakalamamıştı.

## 2026-10-08 — Wi-Fi (isteğe bağlı), basılı tutma her yerde ana sayfa, Menü'de sola kalma (firmware 1.10.0)
- Wi-Fi: kullanıcı isteğiyle eklendi; önceki "cihaz Wi-Fi kullanmaz" kuralı değişti (AGENTS.md). 1.11.0'da yeniden kaldırıldı (aşağıda). Ağ adı ve şifre ayar sayfasındaki Cihaz ayarları → Wi-Fi kartından gönderilir (wifi_scan, wifi_set, wifi_status, wifi_on, wifi_forget). Şifre yalnız cihazda (NVS vdwifi) durur, hiçbir yanıtta geri gönderilmez; uygulama saklamaz. Şifre boş (açık ağ) ya da 8–63 karakter.
- Ağ kaydedilmedikçe radyo kapalı. Bağlanınca NTP (pool.ntp.org, time.google.com) saati verir; masaüstü uygulaması 6 saattir saat göndermediyse cihaz saati NTP'den alır. Yerel saat farkı uygulamanın son "time.tz" değerinden saklanır (varsayılan +3 saat).
- Bluetooth ile birlikte çalışmak için modem uyku açık kalır (WiFi.setSleep(true); kapatılırsa ESP-IDF çöker). Bağlanamazsa 20 sn sonra "Bağlanamadı", dakikada bir yeniden dener.
- Bellek: Wi-Fi kütüphanesi bağlanınca statik RAM 75,3 KB'tan 96,0 KB'a çıktı (+20,7 KB, Wi-Fi kapalıyken de); radyo açıkken yığın yaklaşık 50 KB daha kullanır. 1.8.x'teki "Cihaza yaz" paniği bellek kaynaklıydı; hello'daki heap / block izlenmeli.
- Cihazda Bağlantılar sayfasının alt satırı Wi-Fi durumunu gösterir (ağ, sinyal, bağlanıyor / bağlanamadı); B tuşu Wi-Fi'yi açar / kapatır (ağ kayıtlıysa).
- Döndürgeci basılı tutmak her ekranda ana sayfaya döner; açık modlar kapanır (ses ayarı, Bağlantılar ve Menü imleci). Eşleştirme modu arka planda süresini doldurur.
- Medya: A basılı → sessiz aç / kapat, B basılı → ses modu (çevirerek ses; tekrar B basılı ya da 6 sn ile biter). Kısa A / B önceki / sonraki. Diğer ekranlarda A / B'yi basılı tutmak kısa basma gibi çalışır.
- Ses ve parlaklık: ayar modundan çıkış artık basılı tutma değil; mod 6 sn sonra kendisi kapanır, basılı tutma ana sayfaya götürür. Bağlantılar ve Menü'de imleç basılı tutmayla kapanmak yerine ana sayfaya dönülür.
- Menü'de sola çevirmek Menü'de bırakır (son uygulamaya geçmez). Menüden açılan bir ekranda sola çevirmek Menü listesine döndürür; sağa çevirmek ana sayfaya.

## 2026-10-08 — Wi-Fi ağları kendiliğinden listelenir (firmware 1.10.1)
- Sorun: Wi-Fi kartı düğmeleri çizildiği anki bağlantı durumuna göre kapatıyordu; sayfa cihaz bağlanmadan çizildiyse "Ağları tara" kapalı kalıyordu. Ağ adı da elle yazılıyordu.
- Kart cihazı bekler (1,5 sn'de bir); cihaz bağlı ve firmware ≥ 1.10.0 olunca, Cihaz ayarları sekmesi açıksa ağları kendisi tarar. Liste sinyale göre sıralı; ağa tıklayınca altında şifre alanı ve Bağlan açılır (açık ağda şifre yok). Elle ağ adı alanı kaldırıldı. Eski firmware'de "Firmware yükle" düğmesi çıkar.
- Tarama sonucu ve açık ağ yeniden çizimlerde korunur; en çok dakikada bir tarama (sayfa her düzenlemede yeniden çiziliyor, cihaz taramada 2–4 sn meşgul).
- Cihaz Wi-Fi'yi başlatamazsa (bellek) wifi_scan "scan_failed" ve heap döner; sayfa bunu "Cihaz Wi-Fi'yi başlatamadı" diye gösterir.

## 2026-10-08 — Wi-Fi kaldırıldı, saat Wi-Fi'siz korunur, ek bellek teşhisi (firmware 1.11.0)
- Kullanıcı Wi-Fi'yi deneyemedi: tarama "bellek yetmedi" ile başlamadı. Karar (kullanıcı): Wi-Fi tamamen kaldırıldı. Wifi.h, wifi_* komutları, ayar sayfasındaki Wi-Fi kartı ve Bağlantılar'daki Wi-Fi satırı silindi; Bağlantılar listesi bir satır büyüdü (6 satır). Statik RAM 96,0 KB → 75,3 KB.
- 1.10.x'te cihaza kaydedilmiş ağ adı ve şifre (NVS vdwifi) açılışta silinir.
- Saat: uygulamadan gelen her "time" çipin kendi saatini de ayarlar (settimeofday). Bu saat yeniden başlatma, çökme ve derin uykuda ("Kapanıyor") sürer; uygulama bağlanmadan da saat ve otomatik tema doğru açılır. Saat dilimi değişince NVS vdclk/tz'ye yazılır (varsayılan +3 saat). Yalnız pil tamamen biterse uygulama bağlanana kadar saat yok. Derin uykuda çipin iç RC saati kullanıldığından uzun uykudan sonra birkaç dakika kayabilir; uygulama bağlanınca düzelir.
- Ek bellek teşhisi: hello'da embPsram (çip paketinde PSRAM var mı, esp_chip_info CHIP_FEATURE_EMB_PSRAM), psramInit (esp_psram_is_initialized), chipRev, flashMB. Ayar sayfası Cihaz özetinde "Bellek" çipi ve bağlantı kaydında teşhis satırı. Çipte PSRAM var ama başlamıyorsa yazılım tarafı, yoksa kart PSRAM'sız bir sürüm.

## 2026-10-08 — Ek bellek (PSRAM): çipe uygun yazılım, ek bellek yokken ikon önbelleği, Bellek kartı (firmware 1.12.0)
- Derleme OPI (qio_opi, CONFIG_SPIRAM_MODE_OCT) için doğruydu ve esp_psram_init firmware'de vardı; yine de kart 0 MB bildiriyordu. OPI yazılımı 2 MB'lık quad (QSPI) ek belleği başlatamaz (klon kartlarda ESP32-S3R2 olabilir), QSPI yazılımı da octal belleği başlatamaz.
- Artık iki derleme var: firmware/bin (OPI) ve firmware/bin-qspi (QSPI; Arduino psramInit ile çalışma anında arar, bulamazsa ek belleksiz devam eder). tools/build_firmware.sh ikisini de derler (build.psram_type=opi / qspi). embed_firmware.py FIRMWARE.parts (OPI) ve FIRMWARE.qspi'yi gömer (app/index.html ~3,8 MB).
- "Firmware yükle" esptool-js ile çipin eFuse PSRAM_CAP alanını okur: 1 = 8 MB OPI → OPI, 2 = 2 MB QSPI → QSPI, 0 = yok → QSPI (harici quad bellek varsa onu da bulur); okunamazsa OPI (LilyGO kartı). Seçim yükleme kaydına yazılır.
- hello: psramCap, psramVendor (eFuse), fwPsram ("opi" / "qspi"), embPsram, psramInit, heap, block.
- Ek bellek yokken uygulama ikonları artık açılışta RAM'e yüklenmez (16 uygulama ≈ 51 KB). 6 yuvalı önbellek (≈ 19 KB) ekrandaki ikonları /icons/<id>.bin'den çizilirken yükler, en eski çizileni çıkarır; applyConfig önbelleği de boşaltır. Ek bellek varsa ikonlar eskisi gibi ek bellekte.
- Ayar sayfası Cihaz ayarları → "Bellek" kartı: ek bellek durumu, çipteki ek bellek, yüklü yazılım tipi, boş iç bellek ve en büyük parça (çubuk), duruma göre açıklama; yazılım çipe uymuyorsa "Uygun yazılımı yükle". Her status olayında (5 sn) güncellenir; "Yenile" hello'yu yeniden okur.

## 2026-10-08 — Ek bellek gerçekten açıldı: BOARD_HAS_PSRAM (firmware 1.12.1)
- Asıl neden: `lilygo_t_display_s3` kart tanımı `BOARD_HAS_PSRAM` vermiyor. Arduino-ESP32 3.x `esp32-hal-psram.h` içinde bu tanım yoksa `CONFIG_SPIRAM`'i siliyor; `psramFound()` hep false, `ps_malloc` / `ps_realloc` hep NULL, `ESP.getPsramSize()` hep 0 oluyordu. ESP-IDF ise ek belleği açılışta başlatıp yığına ekliyordu (1.11.1'in ara derlemesi `heap_caps_get_total_size(MALLOC_CAP_SPIRAM)` ile 8192 KB okudu): 4 KB'tan büyük sıradan malloc'lar zaten ek bellekteydi, ama ekran tamponu, animasyon, ikonlar ve satır tamponları iç RAM'de kalıyordu.
- Donanım (esptool, 2026-10-08, Sencer'in kartı): ESP32-S3 (QFN56) rev v0.2, `Embedded PSRAM 8MB (AP_3v3)`, eFuse PSRAM_CAP = 1 (8M), PSRAM_VENDOR = 1 (AP_3v3), flash 16 MB 3.3 V. 1.12.0'ın "QSPI klon kart" varsayımı bu kart için geçerli değil; QSPI derlemesi de aynı `BOARD_HAS_PSRAM` eksikliğiyle derlendiği için çözmüyordu. QSPI derlemesi ve çipe göre seçim kaldırıldı, tek (OPI) derleme.
- 1.11.0'ın `embPsram`'ı yanlıştı: ESP-IDF'nin S3 `esp_chip_info()`'su `CHIP_FEATURE_EMB_PSRAM`'i hiç doldurmaz. Artık eFuse PSRAM_CAP'ten okunuyor (hello: psramCap, psramVendor, embPsram = cap != 0).
- Derleme: `tools/build_firmware.sh` `-DBOARD_HAS_PSRAM` verir; `Board.h` bu tanım yoksa derlemeyi durdurur. arduino-cli çekirdek önbelleğini (`core.a`) derleme bayraklarına bakmadan anahtarlıyor; 5 Ekim'den kalan bayraksız `core.a` yeniden kullanılıyordu. Betik `ARDUINO_BUILD_CACHE_PATH`'i bayrakların özetine göre ayırır (`firmware/VolkanDeck/build/cache-<özet>`). Derlenmiş ELF'te `psramFound` / `ps_malloc` 7 baytlık boş gövdeyse PSRAM katmanı yine kapalıdır.
- `psramFound()`'a güvenilmez: `CONFIG_SPIRAM_BOOT_INIT` ile Arduino, açılış başarısız olsa da true döndürür. Firmware `psramOk()` (yığında SPIRAM var mı) kullanır; satır tamponu ek bellek alamazsa iç RAM'e döner (ara derlemede `ps_realloc` NULL döndüğü için seri okuma görevi ilk tamponu sonsuza kadar bekledi, kart komut almadı).
- Ekran tamponu (320×170×2 = 108 KB) önce iç RAM'e konur (panele aktarım ek bellekten daha yavaş); sığmazsa ek belleğe. Animasyon kareleri, ikonlar, kapak, satır ve gönderme tamponları ek bellekte.
- Kartta ölçülen (1.12.1, USB): psram 8192 KB, boş iç RAM 35 → 58 KB, 55 karelik GIF ek bellekte (en büyük boş blok 6271 KB). Cihaza yaz ve Bluetooth çalıştı; GIF kullanıcıya göre biraz daha akıcı (ölçülmedi).
- 1.12.0'dan kalanlar: ek bellek yokken 6 yuvalı ikon önbelleği (artık `psramOk()` ile), ayar sayfasındaki Bellek kartı (QSPI / yazılım tipi satırları çıkarıldı; 1.12.1'den eski firmware'de "Firmware'i güncelle").

## 2026-10-08 — Wi-Fi geri geldi, yalnız uygulamadan (firmware 1.13.0) ve uygulamanın adı Game Deck
- Ek bellek 1.12.1'de açıldığı için 1.10.x'teki Wi-Fi geri alındı (`Wifi.h`). Ağ yalnız ayar sayfasındaki Cihaz ayarları → Wi-Fi kartından seçilir: kart cihaz hazır olunca ağları kendisi tarar (dakikada en çok bir kez), ağa dokununca şifre alanı açılır, "Bağlan" `wifi_set` gönderir. Aç/Kapat (`wifi_on`) ve "Ağı unut" (`wifi_forget`) aynı kartta. Cihazda ayar yok; Bağlantılar sayfasındaki WI-FI satırı yalnız durumu gösterir.
- Şifre yalnız cihazın NVS'inde (`vdwifi`) durur; `wifi_status` / `hello` geri göndermez, uygulama kaydetmez. `wifi_set`: SSID ≤ 32, şifre boş veya 8–63 karakter.
- Bellek: Wi-Fi kütüphanesi sabit iç RAM'i ~20 KB artırır (derlemede 75 → 96 KB). Wi-Fi istenince (açık + ağ kayıtlı) 108 KB'lık ekran tamponu açılışta ek belleğe konur; radyo açılırken iç RAM yetmezse tampon ek belleğe taşınır (`wifiMakeRoom`). Boş iç RAM 45 KB altındaysa radyo açılmaz, durum `nomem` ("Bellek yetmedi"). Modem uykusu açık kalır.
- Saat: bağlıyken NTP (`pool.ntp.org`, `time.google.com`); uygulamanın gönderdiği saat ve saat dilimi yine geçerli. 1.11.0'ın açılışta `vdwifi`'yi silmesi kaldırıldı.
- Uygulamanın görünen adı **Game Deck** (pencere, tepsi, bildirimler, ayar sayfası, kurulum betikleri, cihazın USB ürün adı ve varsayılan Bluetooth adı). Ayarlar kaybolmasın diye `userData` eski "Volkan Deck" klasöründe sabit. Kurulum betikleri `Game Deck.app` / `%LOCALAPPDATA%\Programs\Game Deck` kurar, eski Volkan Deck kurulumunu ve kısayollarını kaldırır. Değişmeyenler: depo adı, `firmware/VolkanDeck`, paket adı `volkan-deck`, bundle id `com.volkan.deck`, macOS imza kimliği "Volkan Deck Yerel" (değişirse izinler yeniden sorulur). Cihazda kayıtlı Bluetooth adı kendiliğinden değişmez.

## 2026-10-08 — Ana ekranda Bluetooth ve Wi-Fi simgeleri (firmware 1.13.1)
- Ana ekranın durum satırında, sayfa sayacı ile bağlantı yazısı (usb / ble) arasında iki küçük simge.
- Bluetooth: bilgisayar bağlıysa mavi + yeşil nokta; açık ama bağlı değilse gri; eşleştirme modunda turuncu; kapalıysa (veya "Sadece USB") gri ve üstü çizili.
- Wi-Fi: bağlıyken beyaz, sinyal gücü 1–3 çizgi (-60 / -72 dBm eşikleri, Bağlantılar sayfasıyla aynı); bağlanırken turuncu; bağlanamadı / bellek yetmedi kırmızı çizili; kapalı veya ağ seçilmemişse gri çizili.
- Durum her 500 ms'de kontrol edilir; değişirse ana ekran yeniden çizilir (tasarruf modunda da).

## 2026-10-08 — Bağlantı yazısı yerine simge (firmware 1.13.2)
- Durum satırındaki "usb" / "ble" / "none" yazısı kaldırıldı. Yerine USB ile bağlıyken beyaz USB simgesi, Bluetooth ile bağlıyken mavi Bluetooth simgesi, bağlı değilken gri ve üstü çizili USB simgesi.
- Ana ekranda Bluetooth durum simgesi zaten olduğu için Bluetooth bağlantısında ayrıca simge çizilmez; USB ve "bağlı değil" simgesi yine görünür.

## 2026-10-08 — iOS tarzı pil göstergesi (firmware 1.13.3)
- Durum satırındaki pil kutusu ve dışındaki "%" yazısı yerine iOS tarzı kapsül: yuvarlak köşeli gövde (soluk iz), seviye kadar dolu, yüzde sayısı gövdenin içinde (dolu kısımda oyuk, boş kısımda açık renk), ayrı küçük kutup başı (tam dolunca seviye renginde).
- Renkler: normal beyaz (açık temada koyu), %20 altında kırmızı, şarj olurken yeşil ve kapsülün solunda yeşil şimşek.
- Kapsül x 284–313, kutup başı 314–316. USB / Bluetooth simgesi 262'ye, ana ekrandaki BT / Wi-Fi simgeleri bir sola kaydı.

## 2026-10-08 — Piksel simgeler; Medya ve Ses ve parlaklıkta döndürgeç sayfanın içinde (firmware 1.13.4)
- Durum satırındaki Bluetooth ve USB simgeleri kenar yumuşatmalı çizgilerden (1.13.2) piksel bitmap'e geçti: 1 px çizgi, yalnız 45° köşegen, yumuşatma yok (`BM_BT` 7×13, `BM_USB` 15×9, `drawBm`). Küçük panelde bulanık görünüyorlardı. "Bağlı değil" çizgisi de pikselli (`pxSlash`). Wi-Fi ve pil olduğu gibi kaldı. Bağlantılar sayfasındaki ve menüdeki büyük Bluetooth simgesi değişmedi.
- Medya ve Ses ve parlaklık sayfalarında döndürgeç artık sayfadan çıkmaz: Medya'da çevirince doğrudan ses değişir; Ses ve parlaklık'ta çevirince seçili değer değişir (başta ses, basınca ses ↔ parlaklık). Çıkmak için uzun basılır (ana sayfa) veya ana sayfaya dönüş süresi beklenir. Medya'da "Ana sayfaya dönme" açıksa (varsayılan) beklemekle dönülmez.
- Medya'da B basılı tutma (ses modu) kaldırıldı; B basılı = B (sonraki şarkı). A basılı = sessiz, aynı kaldı.
- Ayar sayfasındaki önizleme ve kontrol listesi aynı davranışa ve aynı durum satırına güncellendi.

## 2026-10-08 — Bağlantılar'da da döndürgeç sayfanın içinde (firmware 1.13.5)
- Bağlantılar sayfasında döndürgeç çevrilince satır imleci hemen açılır (aktif satırdan başlar) ve satırlar arasında gezer; sayfadan çıkmaz, sola çevirmek de menüye dönmez. Basınca seçili satır uygulanır (bilgisayar seç, yeni cihaz, eşleşmeleri sil). Çıkış: uzun bas veya bekle. Bluetooth kapalıyken / eşleştirme sırasında çevirmek bir şey yapmaz.
- Üst satır ipucu "çevir: seç · A: kapat". Ayar sayfasındaki önizleme ve kontrol listesi güncellendi.

## 2026-10-08 — Wi-Fi taraması arka planda (firmware 1.13.6)
- Belirti: uygulama açılınca ya da ⌘R ile yenilenince kart birkaç saniye donuyor, uygulama bağlantıyı yeniden kuruyordu (Bağlantılar sayfasından bağımsız). Neden: Cihaz ayarları → Wi-Fi kartı her açılışta `wifi_scan` gönderiyor, firmware `WiFi.scanNetworks(false)` ile beklemeli tarıyordu. Bluetooth anteni paylaştığı için tarama kartta 8,9 sn sürdü; bu sürede ana döngü (ekran, komutlar) duruyordu.
- Firmware: `wifiScanStart()` taramayı `scanNetworks(true)` ile başlatır; `protoPoll` başındaki `scanPoll()` bitince cevabı isteğin geldiği yoldan (USB / Bluetooth bağlantısı) gönderir; 12 sn'de bitmezse iptal. Tarama sürerken ikinci `wifi_scan` → `busy`. Ölçüm: tarama sürerken `wifi_status` 33 kez ≤ 55 ms'de cevaplandı.
- Ayar sayfası: Wi-Fi zaten bağlıysa açılışta tarama yok; "Yeniden tara" düğmesi tarar.
- `Wifi.h` → `WifiLink.h`: büyük/küçük harf ayırmayan diskte (macOS, Windows) `#include <WiFi.h>` taslak klasöründeki `Wifi.h`'ı buluyordu; temiz derleme hata veriyordu (eski `includes.cache` ile çalışıyordu).

## 2026-10-08 — Başkasının deck'ine Bluetooth ile bağlanma denemesi (uygulama)
- Belirti: Sencer'in deck'i kendi Mac'ine USB ile bağlıyken, aynı odadaki Volkan'ın Mac'inde belirli aralıklarla "Sencer Deck'e bağlanılsın mı?" penceresi çıkıyordu; cihaz eşleştirme modunda değildi.
- Neden: kabloyla bağlı olmayan bilgisayarda uygulama Bluetooth veri kanalını 12 sn / 30 sn / 1 dk, sonra 5 dk aralıkla dener. Seçici yalnız servis UUID'sine bakıp `list[0]`'ı alıyordu, yani menzildeki herhangi bir Game Deck'i. "Bu bilgisayar cihazla eşleşmiş mi?" kapısı yalnız Windows'taydı (`blePaired`, 1.8.5); macOS'ta hep `true` döndüğü için eşleşmemiş deck'e bağlanılmaya çalışılıyor, macOS da deck'in sahibi olmayan Mac'te eşleştirme penceresi açıyordu. Cihaz ayrıca eşleştirme modunda olmasa da hep bağlantıya açık reklam yayınlar (bağlı bilgisayarlar ve masaüstü uygulaması bulabilsin diye); bu değişmedi, firmware'e dokunulmadı.
- Çözüm (yalnız `app/`): `app/ble-pick.js`. macOS'ta `blePaired` `system_profiler SPBluetoothDataType -json` ile bu Mac'in eşleşmiş cihazlarına bakar; ayarlardaki cihaz adı yoksa Bluetooth hiç denenmez (Windows'taki gibi, sorulamazsa engellenmez). Seçici artık `list[0]` değil, ayarlardaki adı taşıyan cihazı seçer; ad uyuşan yoksa 8 sn sonra vazgeçer.
- Sınır: kapı cihaz adına dayanır (Windows'taki gibi). İki deck aynı adı taşırsa ve bu bilgisayar birine eşleşmişse ayırt edilemez; kullanıcı deck adlarını farklı vermeli.
- Güncelleme gelene kadar çözüm yolu: Ayarlar → Cihaz → Bağlantı = "USB" (`device.connection:"usb"`) uygulamanın Bluetooth denemesini kapatır.

## 2026-10-09 — Karartılmış ekranda ilk dokunuş da çalışır (firmware 1.13.7)
- Ekran karartılmış ya da güç tuşuyla kapatılmışken döndürgeç veya bir tuş eskiden yalnız ekranı uyandırıyor, işlem ikinci dokunuşta yapılıyordu. Artık ekran uyanır ve aynı dokunuş hemen uygulanır (`wakeUp()` girdiyi yutmaz). Güç tuşu aynı kaldı: kısa bas ekranı açar / kapatır, uzun bas kapatır.

## 2026-10-09 — Şarj aletinde Bluetooth devrede kalır (firmware 1.13.8)
- Otomatik bağlantıda USB, kablonun ucunda bilgisayar olduğu bilinince önceliklidir: masaüstü uygulaması (veya ayar sayfası) USB seri üzerinden bir satır gönderdiyse (`usbPcSeen`) ya da bir program seri portu açtıysa (`Serial`). Şarj aleti, TV, konsol, monitör portu cihazı yalnız besler / tanır; o zaman Bluetooth bağlıysa tuşlar ve olaylar Bluetooth'tan gider. Bluetooth da yoksa USB'ye düşer (eskisi gibi).
- `usbPcSeen` her yeni USB oturumunda (STARTED) ve kablo çıkınca (STOPPED) sıfırlanır. "Sadece USB" / "Sadece Bluetooth" ayarları değişmedi.
- Sınır: uygulaması kapalı bir bilgisayara takılı kabloda da Bluetooth öne geçer (bilgisayarı başka cihazdan ayırt edecek sinyal yok); uygulama açılınca USB'ye döner.

## 2026-10-09 — Döndürgeç listenin sonunda durur (firmware 1.13.9)
- Sağa çevirirken son uygulamaya gelince liste orada durur; ana sayfaya atlamaz. Sola: ana sayfada menü açılır (menü varsa), menüde kalır. "Listenin sonundan başa dön" ayarı kaldırıldı (yapılandırmadaki `wrap` alanı geriye uyumluluk için duruyor, kullanılmıyor). Ana sayfaya dönmek için uzun bas veya bekle.

## 2026-10-10 — A / B'ye mikrofon ve ses kapatma (firmware 1.14.0)
- Hızlı tuş kimliklerine `__mic` (mikrofonu kapat / aç) ve `__mute` (bilgisayarın ses çıkışını, kulaklık / hoparlör, kapat / aç) eklendi. Uygulama ve menü ekranı seçimlerinin yanında Buton A / B düzenleyicisinde seçilir.
- Mikrofon yalnız masaüstü uygulamasıyla çalışır (klavyede standart tuşu yok); ses kapatma uygulama yoksa sessiz medya tuşunu gönderir. Basınca kısa bildirim çıkar ("Mikrofon kapalı / açık", "Ses kapalı / açık").
- Ana ekranda ve uygulama ekranlarında A / B satırı küçük mikrofon / hoparlör rozeti gösterir; kapalıyken rozet ve yazı kırmızı ("Mikrofon kapalı", "Ses kapalı"). Medya ve Ses ve parlaklık sayfalarında A / B o sayfanın kendi işini yapmaya devam eder.

## 2026-10-10 — Yuvarlak, arka planı görünmeyen uygulama ikonları (firmware 1.14.1)
- Sorun: ayar sayfası program ikonlarını koyu #1E232C kareye oturtup gönderiyordu; açık temada her ikonun arkasında koyu kare görünüyordu.
- Ayar sayfası artık ikonun saydam piksellerini tam #1E232C (RGB565 0x1905) yapar, yarı saydam kenarları koyuya karıştırmaz (alfa ≥ 128 opak, altı saydam). Gerçek bir piksel aynı renge düşerse bir adım kaydırılır. Biçim değişmedi: eski firmware aynı görüntüyü gösterir.
- Firmware 0x1905 ve 0xF81F piksellerini çizmez, ikonu 40 px karenin içinde 16,4 px yarıçaplı daireye keser (kare ve yuvarlak köşeli ikonlar da daire olur) ve dış halkayı balon rengine yumuşatır. Böylece ikon her iki temada temanın kendi balon rengi üzerinde durur. Ana ekrandaki 14 px küçük ikon da yuvarlak ve saydam köşeli.
- Ayar sayfasındaki önizleme ve uygulama listesi ikonları da yuvarlak (listede bütün ikonlar daire).
- Cihazdaki ikonlar "Cihaza yaz" ile yeniden gönderilir; eski ikonlarda saydam bölgeler zaten 0x1905 olduğu için güncellemeden sonra kareler hemen kaybolur, yalnız kenarda ince koyu çizgi kalabilir (bir kez Cihaza yaz ile düzelir).

## 2026-10-10 — İkon balonun içini doldurur (firmware 1.14.2)
- 1.14.1'de ikon 40 px karenin içinde 16,4 px yarıçapla kesiliyor, büyük balonda (66 px) küçük ve kırpılmış kalıyordu. Artık ikon renkli halkanın içini tamamen doldurur: büyük balonda 62 px, yandaki balonlarda 38 px çapında daire; 40 px kaynak çift doğrusal (bilinear) büyütülür, kenar yumuşak, halka ikonun kenarını örter. Ana ekrandaki 14 px ikon da daireyi doldurur.
- Ayar sayfası ikonu göndermeden önce saydam kenar boşluğunu kırpar (alfa ≥ 128 piksellerin kutusu, kare, ortalanmış), böylece çizim balonu doldurur. Önizleme de aynı kırpmayı ve dolguyu kullanır.
- Biçim aynı (40×40 RGB565). Kenar kırpması için "Cihaza yaz" ile ikonlar bir kez yeniden gönderilmeli; göndermeden de ikonlar büyür ama kenar boşluğu kalır.
- Bedel: 40 px'ten 62 px'e büyütme biraz yumuşak görünür; daha keskin olması için ikon çözünürlüğü (biçim) ileride artırılabilir.

## 2026-10-10 — Kare ikonlar da tam daire (ayar sayfası, firmware değişmedi)
- Cihaz 40 px ikonun iç teğet dairesini halkanın içine çizer (1.14.2); ikonun bu daireyi kaplaması gerekir. Ayar sayfası ikonu gönderirken (ve önizlemede) artık: 1) saydam kenar boşluğunu kırpar; 2) kare, yuvarlak köşeli kare, macOS tarzı ikonu dairenin %98,5'ini kaplayana kadar en çok 1,3 kat yakınlaştırır (köşeler zaten görünmez); 3) bu yetmiyorsa (arka planı olmayan logo) ikonu uygulamanın rengiyle dolu bir dairenin üstüne %70 boyutla koyar; renk logoya çok yakınsa koyu (#2A2F38) ya da açık (#F2F3F5) zemin seçilir.
- Uygulama listesindeki ikonlar da bu sonucu gösterir. Cihaza "Cihaza yaz" ile gider.

## 2026-10-10 — 64 px ikonlar: cihaz önizlemeyle aynı (firmware 1.15.0)
- Sorun: önizleme ikonu yüksek çözünürlüklü kaynaktan çiziyordu, cihaz ise 40×40 veriyi 62 px'e büyütüyordu; cihazdaki ikon önizlemeden belirgin biçimde bulanık ve farklıydı.
- İkon biçimi 64×64 RGB565 (8192 bayt) oldu; büyük balonda (62 px) neredeyse 1:1 çizilir. `icon_set` 64 veya 40 kabul eder (boyuttan anlaşılır: 8192 / 3200 bayt), `/icons/<id>.bin` dosya boyutuyla okunur, `App.pixN` kenarı tutar. Eski 40 px ikonlar çalışmaya devam eder.
- Ayar sayfası cihaz 1.15.0 veya yeniyse 64 px, değilse 40 px gönderir. Yeni eklenen ikonlar 128 px saklanır (önce 80 px). Önizleme cihaza giden aynı 64 px pikselleri kullanır; cihazın çizimi tarayıcıda taklit edilerek önizlemeyle karşılaştırıldı.
- Bellek: PSRAM'de ikon başına 8 KB (16 uygulama 128 KB); PSRAM yoksa ekrandaki 6 ikon iç RAM'de (en çok 48 KB). Komut satırı tamponu 128 KB, ikon satırı ~11 KB.
- Cihazdaki ikonların keskinleşmesi için firmware yüklendikten sonra "Cihaza yaz" gerekir (ikonlar 64 px yeniden gönderilir).

## 2026-10-10 — Cihaz yeniden başlayınca uygulama Bluetooth'a kendisi döner (uygulama, firmware değişmedi)
- Sorun: cihaz yeniden başlatılınca / kapatılıp açılınca masaüstü uygulaması Bluetooth'a dönmüyordu, uygulamayı kapatıp açmak gerekiyordu.
- Nedenler: 1) `send()` yanıt süresini yazma bittikten sonra başlatıyordu; yeniden başlayan cihaza Bluetooth yazması asılı kalınca `connect()` ve otomatik bağlanma döngüsü (`connecting`) sonsuza kadar bekliyordu. 2) `openBlePort` adımlarında (cihaz arama, gatt.connect, servis, bildirim, yazma) süre sınırı yoktu. 3) Yarı açık kalan bağlantı (hiçbir şey gelmiyor) hiç fark edilmiyordu; port dolu göründüğü için yeniden bağlanılmıyordu. 4) Başarısız denemeler 12 sn → 30 sn → 1 dk → 5 dk geri çekiliyordu.
- Çözüm: `send()` süresi yazmadan önce başlar; Bluetooth adımlarına süre sınırı (20/15/10/5/10 sn, yazma 6 sn) — aşılırsa bağlantı kapatılır. Bekçi: Bluetooth'ta 10 sn hiçbir satır gelmezse `hello` sorulur, yanıt yoksa bağlantı kapatılıp yeniden kurulur. Bağlantı düşünce 3 dakika boyunca 4 sn'de bir denenir (geri çekilme sıfırlanır). 60 sn'den uzun süren bağlanma denemesi sıfırlanır.

## 2026-10-11 — Ana sayfada saat, üç kart; Kartlar ekranı listeden açılıp kapanır (firmware 1.15.1)
- Ana sayfanın durum satırında sayfa numarası (ve renkli nokta) yerine saat (SS:DD) yazar; diğer ekranlarda numara kalır. Tasarruf modunda dakika değişince yalnız bu alan (x 134–211) yenilenir.
- `home.cards` 2 veya 3 kart alır. Üçüncü kart seçilince kartlar alt alta 49 / 49 / 51 px yüksekliğinde sıkışık çizilir (CPU / GPU: sıcaklık, eğri, çubuk; Ağ: indirme büyük, yükleme sağda, ping üstte; Saat, Hava, Döviz için de sıkışık düzen). Eski firmware ilk iki kartı okur.
- Ayar sayfası: Ana sayfa → Kartlar'da "Kart 3 · isteğe bağlı" (Yok / kart seçimi). Soldaki listede Kartlar satırında aç / kapat anahtarı (`pages.widgets.enabled`, "Döndürgeç listesinde göster" ile aynı ayar).

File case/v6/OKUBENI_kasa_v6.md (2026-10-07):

# Volkan Deck – Kasa v6: güçlü ekran tutucu

v4 gövdesinin dışı aynı; ekran tutucu, USB-C girişi, ayak yuvaları ve döndürgeç düğmesi yenilendi. Arka kapak (v5) ve tuş iticileri aynen kullanılır.

## Neden
v4'te kart, ön yüze dik duran 4 ince (1,2 mm) tırnakla tutuluyordu. Gövde yüzü tablada basıldığı için bu tırnaklar katman çizgilerine dik yük alıyor ve kolayca kırılıyordu. Ekranın solundaki tuşlara basmak kartı içeri ittiği için ekran da yerinden çıkıyordu.

## Yeni sistem (vida yok, esneyen parça yok)
- Kartın 4 köşesinin yanında, ön yüzden yükselen kalın **direkler** var. Kartı yanlardan da ortalarlar (her yanda 0,12 mm boşluk).
- Kartın iki ucuna, PCB'nin arkasından **baskı çubuğu** oturur. Çubuklar düz basılır, sağlamdır.
  - **Sol çubuk:** iki köşeye ve B tuşunun tam arkasına bastırır. Ortası USB-C ile pil soketinin üstünden köprü gibi geçer.
  - **Sağ çubuk:** kartın boş olan sağ ucuna boydan boya bastırır.
- Her çubuk ucu, direğe **1,75 mm filamentten kesilmiş bir pimle** kilitlenir (4 pim). Pim deliği, çubuğu karta 0,1 mm bastıracak kadar kaydırılmıştır; bu yüzden boşluk yoktur.
- Tuşa basınca kart çubuğa, çubuk pime, pim de direğe dayanır. Yükü taşıyan hiçbir yerde ince tırnak yoktur.
- Pil fişi için USB kanalının ucunda, tünelin altında bir çentik açıldı (soket kartın ucuna bakıyor).

## USB-C girişi
Eski 14 × 9 mm'lik, üstü üçgen tepeli delik yerine **12,4 × 7,2 mm, köşeleri R1,2 düz bir dikdörtgen** açıldı. Tünel de aynı kesitte ve sokete kadar kapalı, dışarıdan kasanın içi görünmüyor. Fişin plastik başı 12 × 7 mm'ye kadar sığar. Baskıda tünelin tavanı 12,4 mm'lik bir köprüdür; P2S bunu desteksiz basar.

## Döndürgeç düğmesi
Ø30 yerine **Ø24 × 18 mm**. Yüksekliği aynı, mili kesmeye gerek yok. Alt kısımda 60 ince tırtıl, üstte düz bir bant ve aradaki V halkası var. Üst yüz 0,6 mm çanak şeklinde; mildeki D düzlüğü yönünü gösteren bir işaret çizgisi var. İç ölçüler v4 ile aynı: somun boşluğu Ø13,6, burç boşluğu Ø7,6, D delik. İçerideki geçişler 45° olduğu için düğme dik, desteksiz basılır.

## Ayaklar
Tabandaki 4 yuva **Ø15 mm yapışkanlı yuvarlak kaydırmaz pedlere** göre: Ø15,6 mm, 1 mm derin, kenardan en az 1 mm içeride (x ±37, y 15 / 72,6). Ped 1 mm'den kalınsa yuvadan taşar ve kasayı masadan kaldırır.

## Parçalar (destek yok)
| Dosya | Adet | Baskı yönü |
|---|---|---|
| v6_govde.stl | 1 | Ön yüzü tablada (v4 ile aynı) |
| v6_baski_cubugu_sol.stl | 1 | Dosyadaki gibi, bacaklar yukarı |
| v6_baski_cubugu_sag.stl | 1 | Dosyadaki gibi |
| v6_dugme.stl | 1 | Dik, alt yüzü tablada (destek yok) |
| v6_pim (3MF'te 6 adet, 2 yedek) **veya** 1,75 mm filament | 4 × 11 mm | Pim: yatık, dosyadaki gibi. Filament: makasla düz kes |

`VolkanDeck_kasa_v6.3mf`: gövde, iki çubuk, düğme ve 6 pim P2S tablasında.
Önerilen ayar: PLA, 0,2 mm katman, **4 duvar** (direkler dolu çıksın), %20 dolgu.

## Montaj
1. Tuş iticilerini ekranın solundaki iki deliğe içeriden takın (v4 ile aynı).
2. Kartı, kablolar bağlıyken, arka açıklıktan ekran yüzüne bastırın. USB-C ucu sol kanala girer, kart dört direğin arasına oturur.
3. Sol çubuğu bacakları karta bakacak şekilde sol uca, sağ çubuğu sağ uca yerleştirin. Uçları direklerin yarıklarına girer.
4. Çubuğu başparmakla karta bastırırken pimi kartın **ortası tarafından** (direğin karta bakan değil, kartın ortasına bakan yüzündeki delikten) sokun ve dibe kadar itin. Pim dışa doğru gider, kör delikte durur.
   - **Basılı pim:** başının 3 mm'lik uzun kenarı ekran yüzüne dik (kasanın içine doğru) dursun; baş direğe dayanınca pim yerindedir.
   - **Filament pim:** 11 mm kesin, ~1,5 mm dışarıda kalır.
5. Pil, arka kapak ve düğme v4'teki gibi takılır.

**Pim sıkı girmiyorsa:** Pimin ucunu biraz eğik kesin ya da çakmakla ısıtılmış bir iğneyle deliği bir kez açın.
**Sökmek için:** Pimi başından (ya da dışarıda kalan ucundan) pense ile çekin.

## Kaynak
`deck_case6.py` (geometri, v4'ü içe aktarır) ve `export6.py` (STL, 3MF ve görseller). Kartın ölçüleri ve bileşen yükseklikleri LilyGO'nun resmî T-Display-S3 3D modelinden alındı. Çubukların kartın arkasındaki hiçbir bileşene değmediği bu modelle kontrol edildi.

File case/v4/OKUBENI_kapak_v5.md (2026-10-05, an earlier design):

# Volkan Deck – Arka kapak v5 (v4 gövdeye takılır)

Gövde değişmedi. Sadece `v5_arka_kapak.stl` dosyasını bas.

## Neden yeni kapak
v4 kapağının 4 tırnağında kanca, kökün hemen dibindeydi. Kapak takılırken tırnağın ~%4 esnemesi gerekiyordu; PLA %2 civarında kırılır. Tırnaklar katman yönüne dik de esniyordu, bu yüzden kırıldılar. Boşluk da yalnızca 0,2 mm'ydi.

## v5'te ne değişti
- **Alt kenar:** 2 sabit dil. Esnemezler. Duvarın arkasına 2,2 mm girerler.
- **Üst kenar:** Kapağın içine açılmış 2 yaylı kol (19 mm). Kapak düzleminde, yani katmanlar boyunca esnerler. Gereken esneme ~%0,7. Kanca 0,7 mm takılır; giriş rampası 30°, tutma yüzü 60°.
- **Dış çerçeve:** Üst ve yan kenarlarda 0,8 mm. Kapağın içeri kaçmasını önler, aralıkları örter. Kapak yüzeyden 0,8 mm çıkıntılı durur.
- **Boşluk:** Kapak ile delik arası her kenarda 0,35 mm.
- **Görünüş:** Dış yüzde üst kenara paralel iki ince yarık var; bunlar yayların boşluğu.

## Baskı (PLA)
- **Yön:** Dış yüz tablada (STL bu yönde). Destek yok.
- **Ayar:** 0,2 mm katman, **4 duvar**. 1,6 mm'lik kol tamamen duvar çizgisinden oluşsun, dolgu olmasın. %20 dolgu yeterli.
- **Tabla:** Dokulu PEI ile dış yüz gövdeyle aynı dokuda çıkar.

## Takma
1. Kapağı üst kenarı dışarı doğru eğik tut, alttaki iki dili gövde açıklığının alt kenarının arkasına sok.
2. Kapağı alt kenar üzerinde döndürerek kapat.
3. Üst kenara bastır; iki kol "tık" diye yerine oturur.

## Sökme
Tırnağını üst kenardaki çerçevenin altına sok ve üst kenarı dışarı çek. Kancalar 60° yüzle tutar, kırılmadan bırakır. Sonra kapağı yukarı kaldırıp alttaki dilleri çıkar.

## Kaynak
`deck_cover5.py`: model ve kontroller (gövde/kart/pil/döndürgeçle çakışma, takarken eğme hareketi).
`export_cover5.py`: STL ve görseller. `section_cover5.py`: kesit görüntüsü.

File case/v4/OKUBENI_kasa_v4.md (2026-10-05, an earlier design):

# Volkan Deck – Kasa v4 (Stream Deck Mini tarzı)

Kompakt bir kama gövde. Bütün kontroller tek bir eğimli yüzde: ekran üstte, altında A ve B tuşları ile döndürgeç. Önden bakınca köşeler R10 yuvarlak, yüzün kenarlarında 45° pah var. Arkada düz, gömme bir kapak bulunuyor.

**Ölçü:** 100 × 85 × 68 mm (G × D × Y). Yüz masaya göre 55° eğimli. Ekran merkezi masadan ~49 mm yüksekte.
**Yerleşim:** A (x −33) ve B (x −11) MX tuşları, döndürgeç x +27 (düğme Ø30 × 18). Ekran ortada üstte, kartın iki tuşu ekranın solunda.

## Pin alanı
- PCB'nin arkasından 25 mm boşluk var. Pin başlıkları, Dupont fişleri ve kablo bükümleri rahat sığar.
- Kart tutucu klipsler yalnızca kartın iki ucunda, pin sıralarına değmez.
- Arka kapak açılınca ekranın arkası, pinler ve pil doğrudan erişilebilir.

## Parçalar (destek yok, tek renk)
| Dosya | Adet | Baskı yönü |
|---|---|---|
| v4_govde.stl | 1 | Ön yüzü tablada (yüz, tabla dokusunu alır) |
| v4_arka_kapak.stl | 1 | Dış yüzü tablada |
| v4_dugme.stl | 1 | Üst yüzü tablada |
| v4_tus_itici.stl | 2 | Modellendiği gibi |

`VolkanDeck_kasa_v4.3mf` dosyasında hepsi P2S tablasına dizili.
Önerilen ayar: PLA veya PETG, 0,2 mm katman, 3 duvar, %15 dolgu.
Dokulu PEI tabla kullanılırsa ön yüz Stream Deck gibi mat ve dokulu çıkar.

## Montaj
1. MX switchleri ön yüze dışarıdan bastırın.
2. KY-040'ı arkadan yerleştirip somununu önden sıkın.
3. Tuş iticileri ekranın solundaki iki deliğe içeriden takın.
4. Kartı, kabloları bağlı olarak, arka açıklıktan ekran yüzüne bastırın. 4 klips tık diye kartı tutar. USB-C ucu sol duvardaki kanala oturur.
5. Pili tabana çift taraflı köpük bantla yapıştırın (alan 62 × 37 × 14 mm).
6. Arka kapağı bastırarak takın; 4 kanca tutar. Sökmek için alt kenardaki çentiği kullanın.
7. Döndürgeç düğmesini mile takın. Tabandaki 4 yuvaya Ø10 lastik ayak yapıştırın.

## USB-C
Sol yan duvarda 14 × 9 mm delik ve karta kadar ~13 mm'lik bir kanal var. Fişin plastik kısmı 14 × 9 mm'den kalınsa kanala sığmaz.

## Dikkat
- Döndürgeç düğmesi D tipi mile göre çizildi.

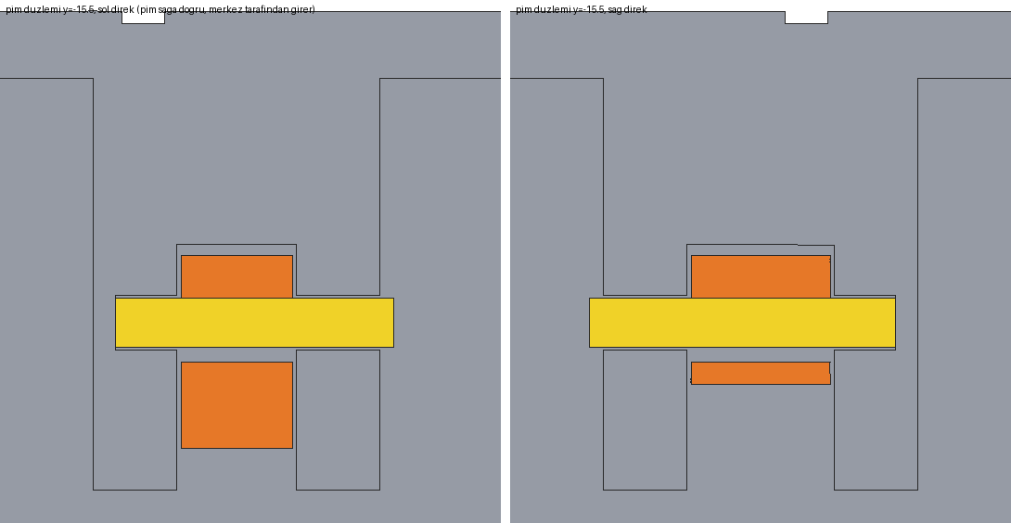
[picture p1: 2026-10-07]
case/v6/v6_pim_kesit.png

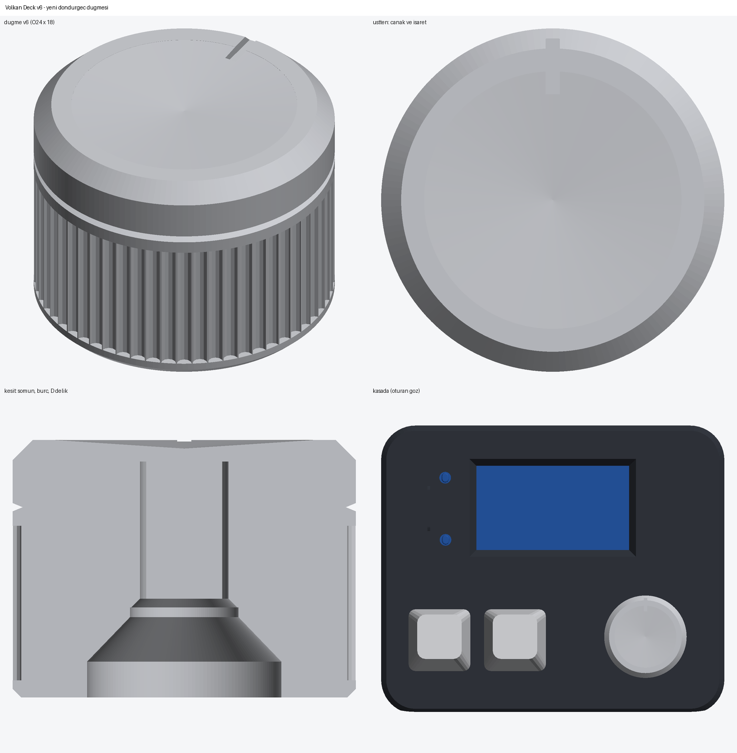
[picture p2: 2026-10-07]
case/v6/v6_dugme.png

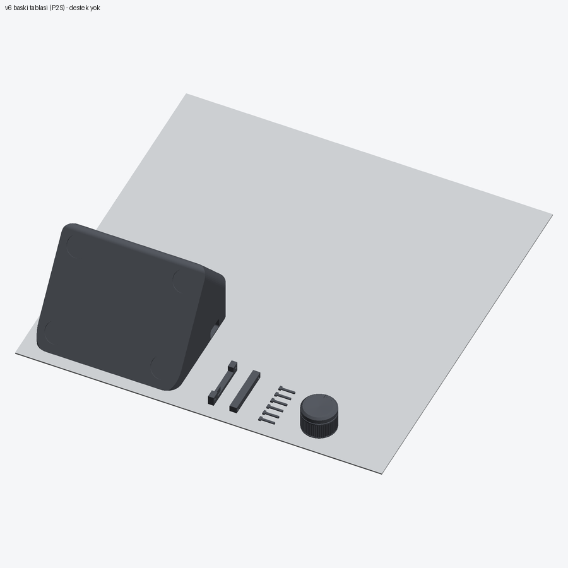
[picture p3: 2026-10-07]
case/v6/v6_plate.png

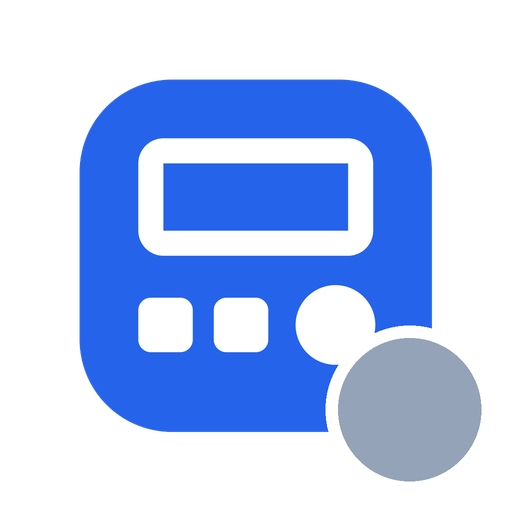
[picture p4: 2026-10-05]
app/dock-off.png

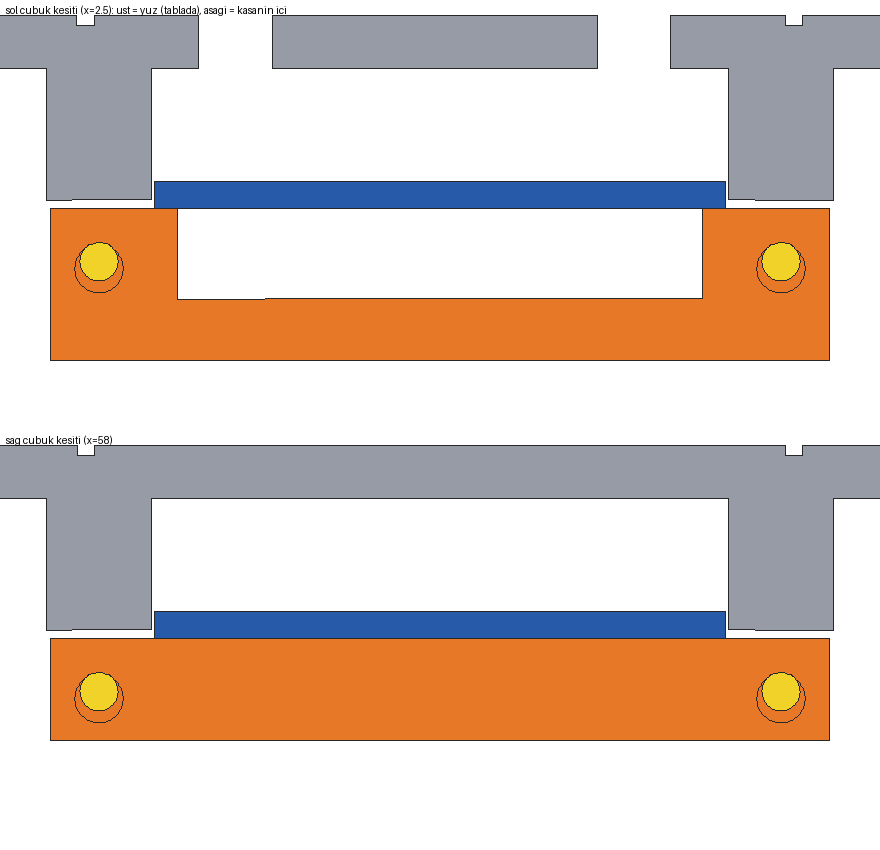
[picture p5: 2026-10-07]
case/v6/v6_kesit.png

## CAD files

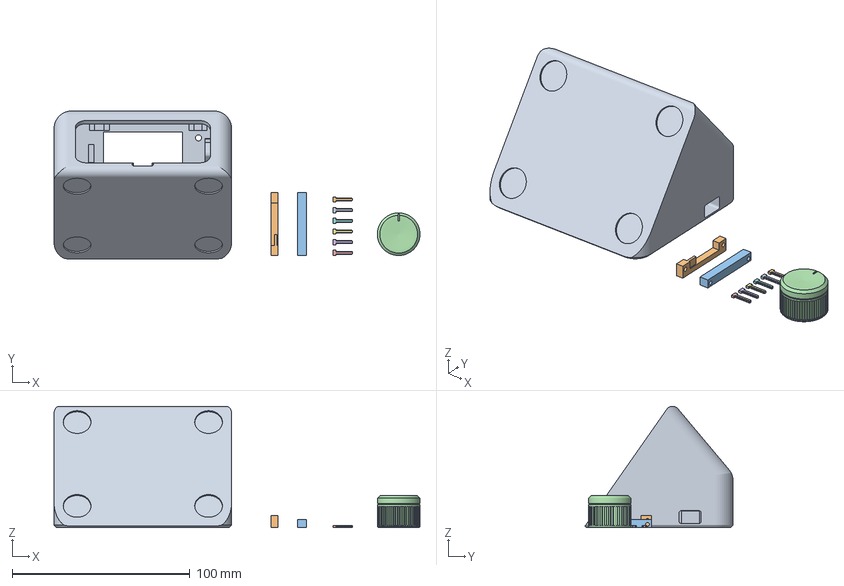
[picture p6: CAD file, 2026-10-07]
case/v6/VolkanDeck_kasa_v6.3mf
206.0 x 83.4 x 68.4 mm
v6_govde
v6_baski_cubugu_sol
v6_baski_cubugu_sag
v6_dugme
v6_pim_1
v6_pim_2
v6_pim_3
v6_pim_4
v6_pim_5
v6_pim_6

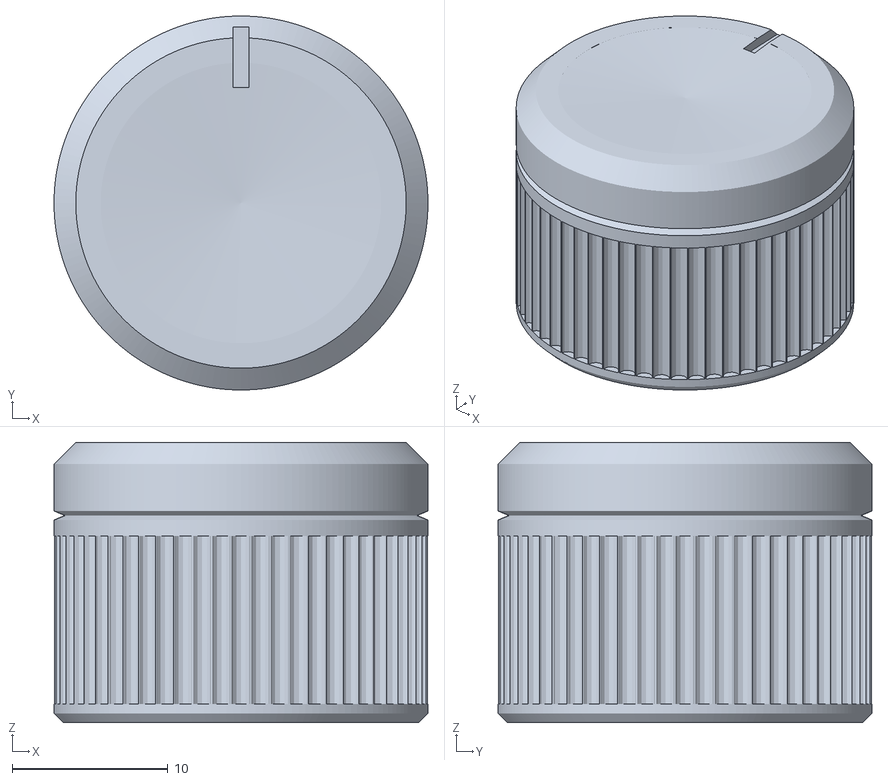
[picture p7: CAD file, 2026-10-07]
case/v6/v6_dugme.stl
24.0 x 24.0 x 18.0

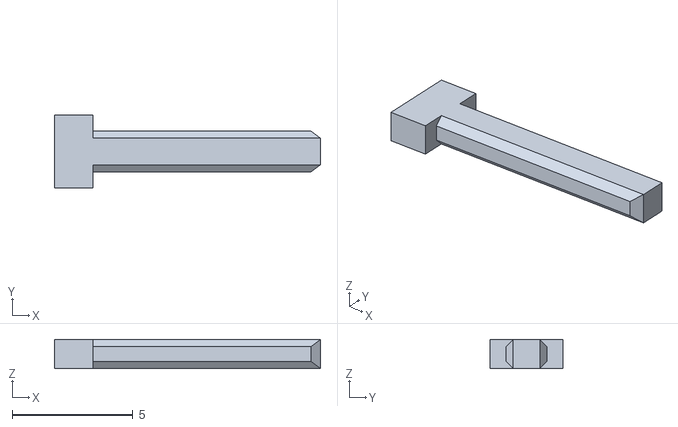
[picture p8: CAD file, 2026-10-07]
case/v6/v6_pim.stl
11.0 x 3.00 x 1.20

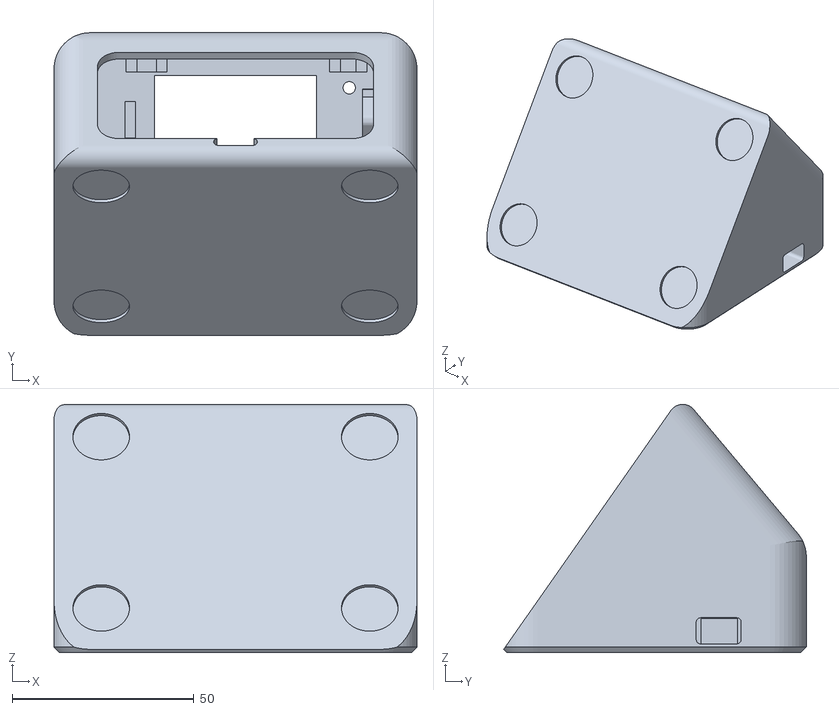
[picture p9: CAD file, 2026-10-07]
case/v6/v6_govde.stl
100.0 x 83.4 x 68.4

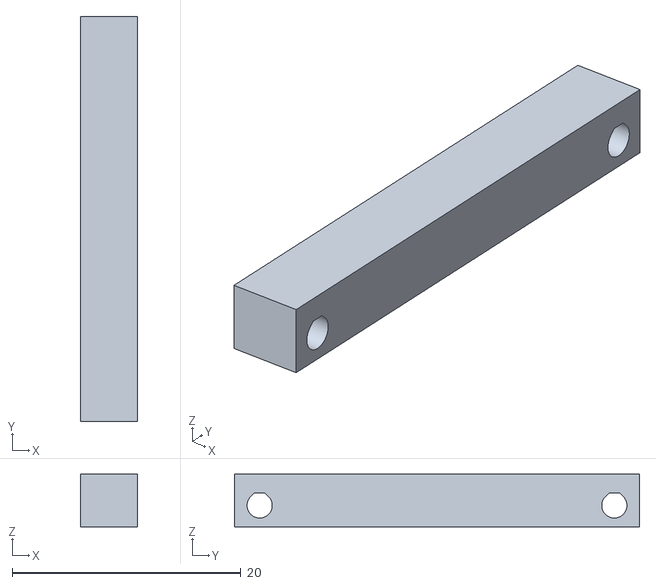
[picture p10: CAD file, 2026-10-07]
case/v6/v6_baski_cubugu_sag.stl
5.00 x 35.4 x 4.62

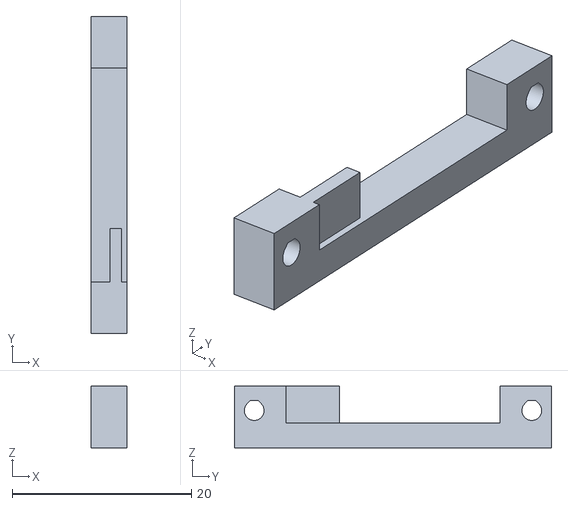
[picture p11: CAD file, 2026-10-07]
case/v6/v6_baski_cubugu_sol.stl
4.00 x 35.4 x 6.92

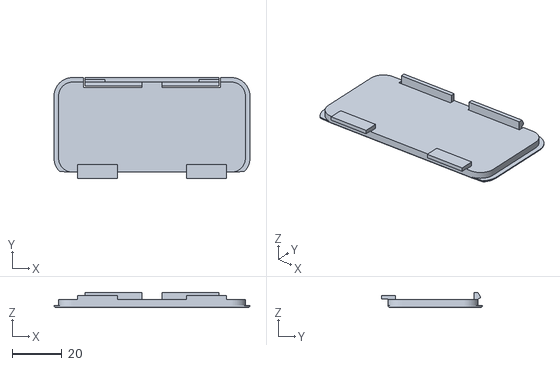
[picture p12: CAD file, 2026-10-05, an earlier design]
case/v4/v5_arka_kapak.stl
79.0 x 40.7 x 6.05

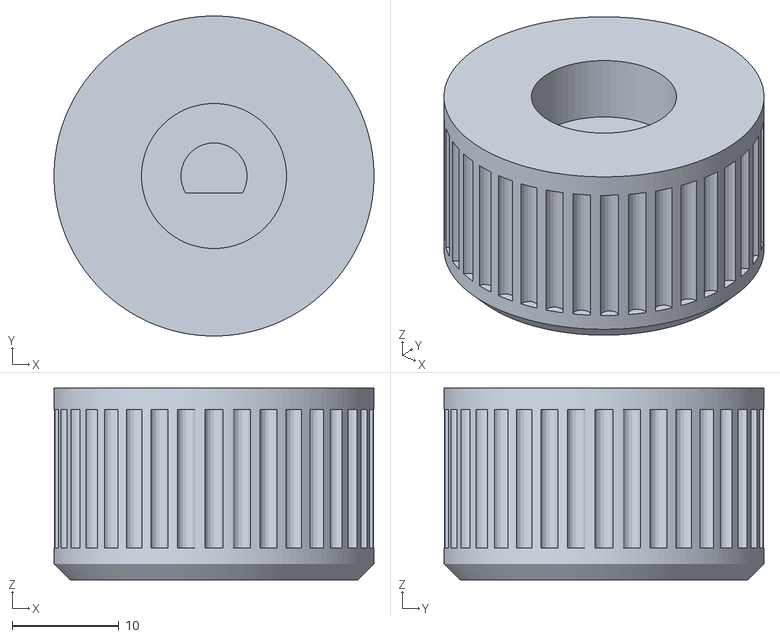
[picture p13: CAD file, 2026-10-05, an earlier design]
case/v4/v4_dugme.stl
30.0 x 30.0 x 18.0

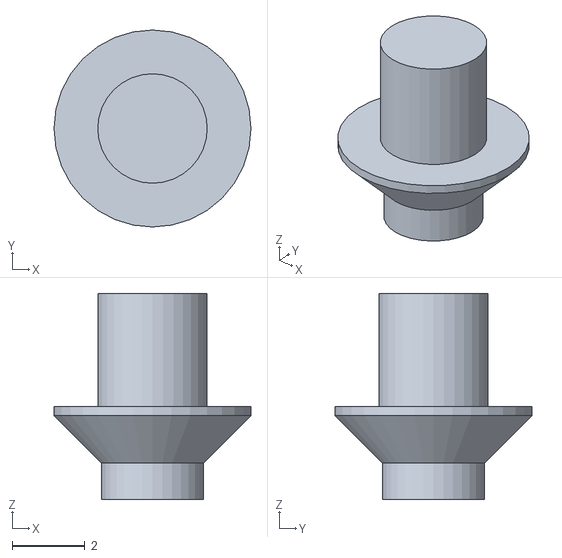
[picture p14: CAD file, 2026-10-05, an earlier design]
case/v4/v4_tus_itici.stl
5.40 x 5.40 x 5.65

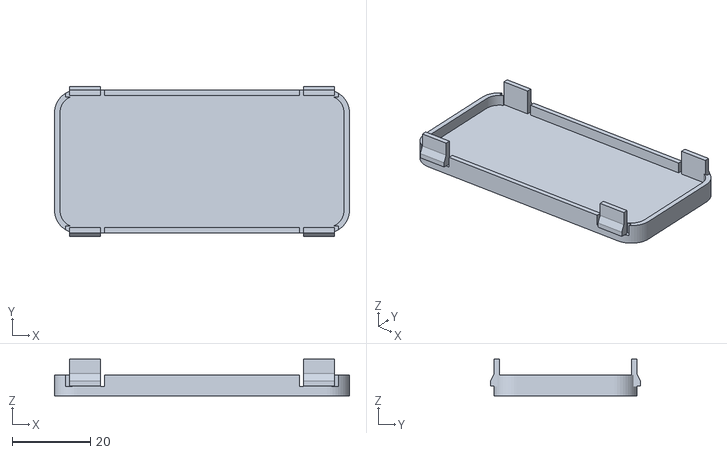
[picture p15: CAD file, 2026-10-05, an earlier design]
case/v4/v4_arka_kapak.stl
75.6 x 38.4 x 9.40

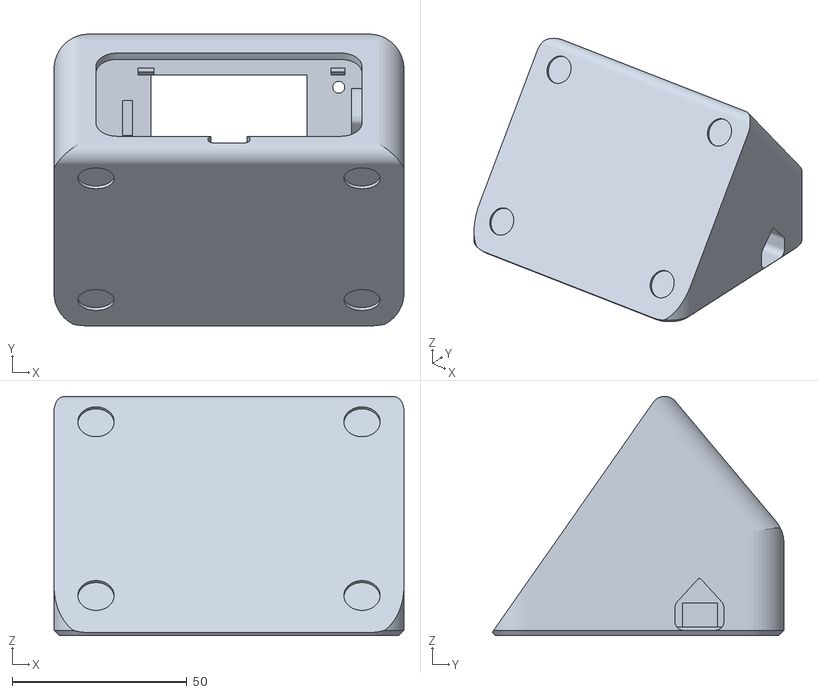
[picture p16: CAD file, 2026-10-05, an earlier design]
case/v4/v4_govde.stl
100.0 x 83.4 x 68.4

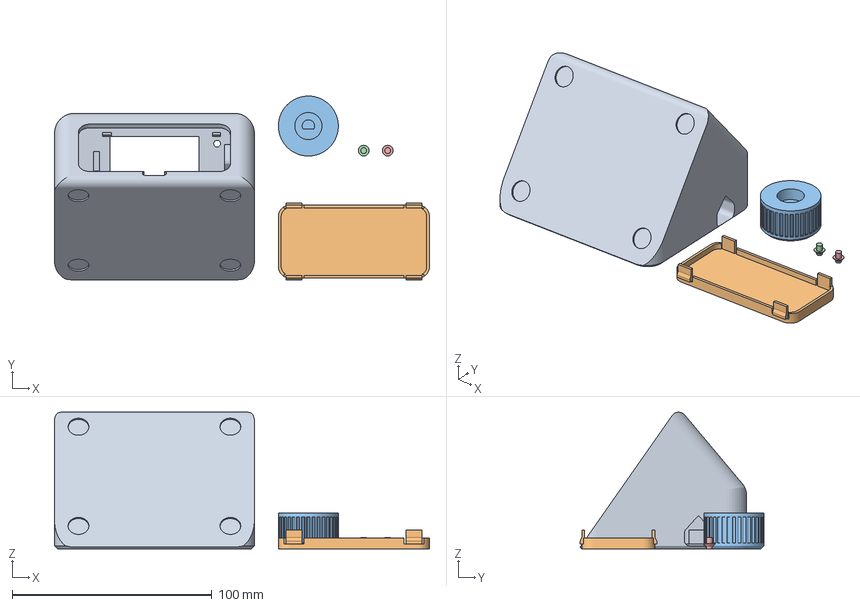
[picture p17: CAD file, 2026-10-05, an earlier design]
case/v4/VolkanDeck_kasa_v4.3mf
187.6 x 92.0 x 68.4 mm
v4_govde
v4_arka_kapak
v4_dugme
v4_tus_itici
v4_tus_itici_2

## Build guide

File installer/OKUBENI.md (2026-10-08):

# Game Deck masaüstü uygulaması (eski adı Volkan Deck) (Windows + macOS)

Uygulama arka planda çalışır. Cihazda bir tuşa bastığında, istediğin programı bilgisayarda kendisi başlatır.

Önceden cihaz programı klavye gibi açıyordu: Win+R kutusunu açıp yazı yazıyordu. Uygulama açıkken bu olmaz; Win+R, Başlat menüsü ya da Spotlight açılmaz. Böylece oyun sırasında odak bozulmaz.

## Ne yapar
- **Bağlantı:** Kart USB ile bağlıysa kendiliğinden bağlanır, kablo çıkıp takılınca yeniden bağlanır.
- **Program açma:** Uygulamaları doğrudan başlatır:
  - **Windows:** .exe, .lnk ve .url dosyalarını, steam:// ve discord:// gibi adresleri açar. Ada göre aramada Başlat menüsü kaydından bulur; Microsoft Store uygulamaları da buna dahil.
  - **macOS:** .app uygulamalarını, adresleri ve ada göre aramayı (Spotlight dizini üzerinden) açar.
- **Ana sayfa kartları:** CPU, GPU, saat, hava durumu, döviz ve ağ verilerini cihaza kabloyla gönderir. Kartın Wi-Fi'ye bağlanmasına gerek kalmaz. Windows'ta CPU sıcaklığı için Cihaz ayarlarından sensör sürücüsü kurulur; NVIDIA GPU ayarsız çalışır.
- **Ayarlar:** Aynı pencerede bütün ayar ekranı var: uygulama ekleme, Cihaza yaz, Firmware yükle.
- **Arka plan:** Pencereyi kapatınca sistem tepsisinde (Windows) ya da menü çubuğunda (macOS) çalışmaya devam eder. Bilgisayar açılınca kendiliğinden başlar; tepsi menüsünden kapatabilirsin.
- **Uygulama kapalıysa:** Cihaz hiçbir şey yazmaz; ekranında "Game Deck uygulaması açık değil" uyarısı çıkar. İstersen Cihaz ayarlarından eski klavye yöntemini (Win+R / Başlat / Spotlight) açabilirsin.
- **Medya (firmware 1.3.0):** Spotify, Apple Music ve YouTube Music'te çalan şarkıyı cihaza gönderir; cihazdaki oynat/duraklat, ileri ve geri tuşları doğrudan o uygulamaya gider. macOS'te ilk seferde "Game Deck, Spotify'ı (Müzik'i, Chrome'u) denetlemek istiyor" izni sorulur: **İzin Ver** de.
- **Ses ve parlaklık (firmware 1.3.0):** Bilgisayarın sesini ve ekran parlaklığını okuyup cihazdan ayarlatır. Windows'ta harici monitör için monitörün menüsünde DDC/CI açık olmalı.
- **Arka planda aç:** Uygulama başına seçenek. İşaretlersen program odağı almadan açılır (Windows'ta simge durumunda, macOS'te arkada).

## Kurulum (bu klasörle)
Kurulum betiği uygulamanın çalışma motorunu (Electron 44.5.1, ~130–150 MB) GitHub'dan indirir ve uygulamayı kurar.

1. **Firmware:** `StreamDeck-Ayar.local.html` ile ya da uygulama kurulduktan sonra Cihaz ayarları → Firmware yükle. Güncel firmware sayfaya gömülüdür.
2. **Windows:** `Windows-Kur.bat` dosyasına çift tıkla.
   - SmartScreen uyarısı çıkarsa: Ek bilgi → Yine de çalıştır.
   - Uygulama `%LOCALAPPDATA%\Programs\Game Deck` klasörüne kurulur; eski `Volkan Deck` kurulumu ve kısayolları kaldırılır, ayarlar korunur. Başlat menüsüne ve masaüstüne kısayol eklenir.
3. **macOS:** Terminal'i aç ve şunu yaz: `bash ` (sonunda bir boşluk bırak). Sonra `Mac-Kur.command` dosyasını Terminal penceresine sürükle ve Enter'a bas.
   - Uygulama `/Applications/Game Deck.app` olarak kurulur (eski `Volkan Deck.app` kaldırılır, ayarlar korunur), bu Mac için imzalanır ve açılır.
4. **Güncelleme:** Uygulama, tepsi/menü çubuğundaki **Güncellemeleri kontrol et** düğmesiyle kendini günceller. Electron sürümü değiştiğinde betiği yeniden çalıştırmak gerekir; ayarlar silinmez.

## Bir uygulamayı doğrudan açtırmak
- **Windows:** "Bilgisayardan seç…" ile eklediğin .exe, .lnk ve .url dosyalarının yolu kendiliğinden kaydedilir.
- **macOS:** "Bilgisayardan seç…" Uygulamalar klasörünü açar; .app seçersin.
- **Elle ayar:** Bir uygulamayı seçince sağ panelde **"Masaüstü uygulamasıyla doğrudan aç"** kutusu çıkar. Orada Windows yolunu ve macOS uygulamasını ayrı ayrı girebilirsin; **Seç…** ve **Dene** düğmeleri var. Aynı cihazı iki bilgisayarda da kullanabilirsin.
- **Ayarları kaydet:** Değişikliklerden sonra **Cihaza yaz**'a bas. Program yolları cihazda saklanır.

## Bilinen sınırlar
- Doğrudan açma yalnızca **USB kablosu** ile çalışır. Bluetooth'ta cihaz klavye yöntemini kullanmaya devam eder.
- "Görev çubuğu sırası" (Win+1…9) ve "Kısayol tuşu" yöntemleri klavye ile gönderilmeye devam eder. Bunlar zaten Win+R gibi bir pencere açmaz.
- macOS'te CPU/GPU sıcaklığı yalnız Apple Silicon'da okunur; Intel Mac'te kartta yük % görünür.
- Firmware yükleme aracı (esptool) ilk kullanımda internetten indirilir.

## Dosyalar
- `Windows-Kur.bat`, `Mac-Kur.command`: Kurulum betikleri.
- `app/`: Uygulamanın kendisi.
- `StreamDeck-Ayar.local.html`: Tarayıcıda açılan ayar sayfası. Güncel firmware içinde gömülü.

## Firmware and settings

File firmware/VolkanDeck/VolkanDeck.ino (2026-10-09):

// Game Deck (formerly Volkan Deck) firmware — LilyGO T-Display-S3 app launcher
// Board: LilyGO T-Display-S3, USB Mode: USB-OTG (TinyUSB), USB CDC On Boot: Enabled
#include "Board.h"
#include "Store.h"
#include "Hid.h"
#include "Stats.h"
#include "WifiLink.h"
#include "Ui.h"
#include "Proto.h"
#include "esp_sleep.h"
#include "esp_system.h"
#include "driver/rtc_io.h"
#include "tusb.h"

static const uint32_t OFF_MAGIC = 0x56444F46;   // VDOF; survives software / watchdog resets too
RTC_NOINIT_ATTR uint32_t offMarker;

static void offSleep() {
  offMarker = OFF_MAGIC;
  Serial.enableReboot(false); tud_disconnect();   // CDCOnBoot starts USB in the core, before setup()
  if (bleStarted) { NimBLEDevice::deinit(true); bleStarted = false; }
  // Keep both display enables low, including during deep sleep (LCD power is RTC GPIO15).
  gpio_set_direction((gpio_num_t)PIN_LCD_BL, GPIO_MODE_OUTPUT);
  gpio_set_level((gpio_num_t)PIN_LCD_BL, 0);
  gpio_hold_dis((gpio_num_t)PIN_LCD_BL);
  gpio_hold_en((gpio_num_t)PIN_LCD_BL); gpio_deep_sleep_hold_en();
  rtc_gpio_hold_dis((gpio_num_t)PIN_LCD_POWER);
  rtc_gpio_init((gpio_num_t)PIN_LCD_POWER);
  rtc_gpio_set_level((gpio_num_t)PIN_LCD_POWER, 0);
  rtc_gpio_set_direction((gpio_num_t)PIN_LCD_POWER, RTC_GPIO_MODE_OUTPUT_ONLY);
  rtc_gpio_hold_en((gpio_num_t)PIN_LCD_POWER);

  esp_sleep_disable_wakeup_source(ESP_SLEEP_WAKEUP_ALL);   // no USB / BLE / timer wake; only BOOT low
  esp_sleep_pd_config(ESP_PD_DOMAIN_RTC_PERIPH, ESP_PD_OPTION_ON);
  rtc_gpio_hold_dis((gpio_num_t)PIN_KEY_PWR);
  rtc_gpio_init((gpio_num_t)PIN_KEY_PWR);
  rtc_gpio_set_direction((gpio_num_t)PIN_KEY_PWR, RTC_GPIO_MODE_INPUT_ONLY);
  rtc_gpio_pullup_en((gpio_num_t)PIN_KEY_PWR); rtc_gpio_pulldown_dis((gpio_num_t)PIN_KEY_PWR);
  // Require a continuous released interval, not just one HIGH sample followed by a delay.
  uint32_t releasedAt = 0; bool released = false;
  for (;;) {
    uint32_t now = millis();
    if (!rtc_gpio_get_level((gpio_num_t)PIN_KEY_PWR)) released = false;
    else if (!released) { released = true; releasedAt = now; }
    else if (now - releasedAt >= 80) break;
    delay(5);
  }
  esp_sleep_enable_ext0_wakeup((gpio_num_t)PIN_KEY_PWR, 0);
  esp_deep_sleep_start();
}

/* ---------- link name for status / protocol ---------- */
const char* linkName() {
  switch (activeLink()) { case L_USB: return "usb"; case L_BLE: return "ble"; default: return "none"; }
}

/* ---------- input ---------- */
volatile int32_t encSteps = 0;           // whole clicks, taken by handleInput()
volatile uint8_t encState = 0, encDet = 4;
volatile int8_t encAcc = 0;
static const int8_t ENC_TAB[16] = { 0, -1, 1, 0, 1, 0, 0, -1, -1, 0, 0, 1, 0, 1, -1, 0 };
void IRAM_ATTR encISR() {
  uint8_t s = (digitalRead(PIN_ENC_CLK) << 1) | digitalRead(PIN_ENC_DT);
  encState = ((encState << 2) | s) & 0x0F;
  encAcc += ENC_TAB[encState];
  // Count only when the knob sits in a detent (both pins high; half-step knobs also rest at both low) and start
  // from zero there: a stray or missed edge can't build up and swallow the first click after a direction change.
  if (encDet <= 1 || s == 3 || (encDet == 2 && s == 0)) {
    int8_t a = encAcc, h = (encDet + 1) / 2;
    encSteps += a >= 0 ? (a + encDet - h) / encDet : -((-a + encDet - h) / encDet);
    encAcc = 0;
  }
}

struct Btn {
  uint8_t pin; bool down = false, raw = false, longFired = false; uint32_t tChange = 0, tDown = 0;
  explicit Btn(uint8_t p) : pin(p) {}
  // returns 1 short (on release), 2 long (fires once while held), 3 released after long, 0 nothing
  int poll(uint32_t longMs) {
    bool r = digitalRead(pin) == LOW; uint32_t now = millis();
    if (r != raw) { raw = r; tChange = now; }
    if (now - tChange < 25) return 0;
    if (r && !down) { down = true; tDown = now; longFired = false; return 0; }
    if (r && down && !longFired && longMs && now - tDown >= longMs) { longFired = true; return 2; }
    if (!r && down) { down = false; return longFired ? 3 : 1; }
    return 0;
  }
};
Btn bEnc(PIN_ENC_SW), bA(PIN_BTN_A), bB(PIN_BTN_B), bPwr(PIN_KEY_PWR), bRst(PIN_KEY_RST);

/* ---------- power / screen ---------- */
uint32_t lastActivity = 0;
bool screenOff = false, dimmed = false;
bool dirty = true;

// Restore the CPU before processing inputs or heavy transfers; no sleep / USB reset.
static void ecoSuspend() {
  if (!ecoActive) return;
#if VOLKAN_ECO_CPU
  if (!setCpuFrequencyMhz(240)) return;
#endif
  ecoActive = false; dirty = true;
}
static void ecoExit() { ecoSuspend(); lastActivity = millis(); }
static void ecoEnter() {
#if VOLKAN_ECO_CPU
  if (!setCpuFrequencyMhz(80)) return;
#endif
  ecoActive = true;
}
int curBright = -1;

static void setBright(int pct) {
  if (pct == curBright) return;
  curBright = pct; lcd.setBrightness(pct <= 0 ? 0 : map(pct, 1, 100, 8, 255));
}

// Wakes a dimmed / switched-off screen. 1.13.7: the input is never swallowed any more, the knob or key
// acts at once (the first press used to only wake the screen). Returns false so callers keep their shape.
static bool wakeUp() {
  ecoExit();
  screenOff = false; dimmed = false; setBright(S.brightness);
  return false;
}

// Battery level. On battery the cell voltage is read through a Li-Po discharge curve. On cable the charger
// lifts the measured voltage (charge current x internal resistance, then 4.2 V hold), so the voltage alone
// would say ~100%. There the level starts from the last battery reading and grows at the charge rate,
// kept between what the measured voltage allows (upper) and its IR-corrected value (lower, CC phase only).
RTC_NOINIT_ATTR static uint32_t socMagic;
RTC_NOINIT_ATTR static float socKept;          // survives software resets (update, crash) while on cable
static const uint32_t SOC_MAGIC = 0x56445343;  // VDSC

static float ocvPct(float v) {
  static const float T[][2] = { {3.30f, 0}, {3.50f, 3}, {3.60f, 8}, {3.68f, 15}, {3.73f, 25}, {3.77f, 35},
    {3.80f, 45}, {3.84f, 55}, {3.88f, 63}, {3.93f, 72}, {3.98f, 80}, {4.04f, 88}, {4.10f, 95}, {4.16f, 100} };
  const int n = sizeof(T) / sizeof(T[0]);
  if (v <= T[0][0]) return 0;
  for (int i = 1; i < n; i++)
    if (v < T[i][0]) return T[i - 1][1] + (v - T[i - 1][0]) / (T[i][0] - T[i - 1][0]) * (T[i][1] - T[i - 1][1]);
  return 100;
}

static void readBattery() {
  static float v = 0, soc = -1;
  static uint32_t tLast = 0, tPlug = 0, tUnplug = 0;
  static bool wasExt = false;
  uint32_t now = millis();
  static float vf = 0;               // fast average: sees the step when a charger starts or stops
  static bool charger = false;       // charger-only cable, found from that step
  static bool wasSusp = false;
  float raw = analogReadMilliVolts(PIN_BAT) * 2 / 1000.0f;
  float vfPrev = vf;
  v = v == 0 ? raw : v * 0.9f + raw * 0.1f;
  vf = vf == 0 ? raw : vf * 0.5f + raw * 0.5f;
  float dt = tLast ? (now - tLast) / 1000.0f : 0; tLast = now;
  // The board has no VBUS sense: pulling the cable from a computer only gives a USB "suspend", the
  // "mounted" flag stays set. So a suspended host does not count as cable, and the voltage step
  // (charge current x cell resistance) marks a charger being plugged in or pulled out.
  bool hostUsb = usbMounted && !usbSuspended;
  if (vfPrev == 0 && vf > 4.25f) charger = true;   // booted on a charger: cell above a resting Li-Po
  if (vfPrev > 0 && vf - v > BAT_STEP_V) charger = true;    // fast average jumped above the slow one
  if (vfPrev > 0 && v - vf > BAT_STEP_V) charger = false;
  if (usbSuspended && !wasSusp) charger = false;    // cable pulled from the computer
  wasSusp = usbSuspended;
  extPower = hostUsb || charger;
  if (soc < 0) {   // first reading after boot
    if (socMagic == SOC_MAGIC && socKept >= 0 && socKept <= 100) soc = socKept;
    else soc = extPower ? ocvPct(v - BAT_IR_V) : ocvPct(v);
  }
  if (extPower) {
    if (!wasExt) tPlug = now;
    float rate = BAT_CHARGE_MA * 100.0f / BAT_MAH / 3600.0f;          // %/s in the constant-current phase
    if (soc > 80) rate *= max(0.15f, (100 - soc) / 20.0f);           // tapering constant-voltage phase
    soc += rate * dt;
    float hi = v < 4.12f ? ocvPct(v) : 100;                            // terminal voltage >= rest voltage
    float lo = v < 4.12f && now - tPlug > 60000 ? ocvPct(v - BAT_IR_V) : 0;
    soc = constrain(soc, lo, hi);
    if (soc > 99.5f) soc = 100;
  } else {
    if (wasExt) tUnplug = now;
    float s = ocvPct(v);
    // after unplugging the cell relaxes for a few minutes: only let the level fall, slowly
    if (now - tUnplug < 180000 && tUnplug) { if (s < soc) soc = max(s, soc - 0.05f * dt); }
    else if (s < soc) soc = max(s, soc - 0.2f * dt);                    // follow drops, smooth load dips
    else if (s > soc + 8) soc = s;                                       // re-sync (e.g. other battery)
  }
  wasExt = extPower;
  socKept = soc; socMagic = SOC_MAGIC;
  batPct = (uint8_t)constrain((int)(soc + 0.5f), 0, 100);
  charging = extPower && batPct < 100;
}

static void goSleep() {
  offMarker = OFF_MAGIC;
  spr.fillSprite(SC_BG);
  text("Kapanıyor", 160, 85, FB18, SC_SUB, textdatum_t::middle_center);
  spr.pushSprite(0, 0); delay(600);
  setBright(0);
  lcd.sleep();
  ledcDetach(PIN_LCD_BL);
  offSleep();
}

/* ---------- navigation & actions ---------- */

static void selectIndex(int i) {
  int n = items.size(); if (!n) return;
  if (S.wrap) i = (i % n + n) % n; else i = constrain(i, 0, n - 1);
  if (i != sel) { sel = i; adjust = 0; subPage = 0; connEdit = false; menuPick = false; dirty = true; evtSelect(); }
}
static Item* curItem() { return items.empty() ? nullptr : &items[sel]; }
// the page on screen: a page opened inside the menu counts as that page
static uint8_t curKind() { Item* it = curItem(); if (!it) return K_APP; return it->kind == K_MENU && subPage ? subPage : it->kind; }
static int menuItemIndex() { for (int i = 0; i < (int)items.size(); i++) if (items[i].kind == K_MENU) return i; return -1; }
static void openPage(uint8_t k) {                // open Medya / Ses ve parlaklık / Bağlantılar inside the menu
  int i = menuItemIndex(); if (i < 0) return;
  if (sel != i) selectIndex(i);
  if (subPage != k) { subPage = k; adjust = 0; connEdit = false; menuPick = false; dirty = true; evtSelect(); }
  auto pages = menuPages();                      // the cursor waits on this page when you come back
  for (int j = 0; j < (int)pages.size(); j++) if (pages[j] == k) menuCur = j;
}
// A / B: an app, or a page of the menu
static void doLaunch(App* a);
static void toggleMic(); static void toggleMute();
static void quickAct(const String& id) {
  if (uint8_t t = quickToggle(id)) {                // 1.14.0: microphone / sound (headphones) on A / B
    if (t == QA_MIC) { toggleMic(); if (sysLive() && sysSt.mic >= 0) toast(sysSt.mic ? "Mikrofon kapalı" : "Mikrofon açık"); }
    else { toggleMute(); toast(sysLive() && sysSt.vol >= 0 ? (sysSt.mute ? "Ses kapalı" : "Ses açık") : String("Sessiz tuşu gönderildi")); }
    dirty = true; return;
  }
  uint8_t pg = quickPage(id);
  if (!pg) { doLaunch(appById(id)); return; }
  bool on = pg == K_MEDIA ? S.mediaOn : pg == K_SYS ? S.sysOn : S.connOn;
  if (!on || menuItemIndex() < 0) { toast(quickPageName(pg) + " ekranı kapalı"); dirty = true; return; }
  openPage(pg);
}
// press on the menu list: first press shows the cursor, the next one opens the page under it
static void menuPress() {
  auto pages = menuPages(); if (pages.empty()) return;
  menuAt = millis(); dirty = true;
  if (!menuPick) { menuPick = true; return; }
  openPage(pages[constrain(menuCur, 0, (int)pages.size() - 1)]);
}

/* ---------- media & system pages ---------- */
bool volPending = false, brightPending = false;

static void mediaAction(const char* act, uint16_t key) {
  mediaFlashAct = act; mediaFlashAt = millis(); dirty = true;
  bool launchPlay = !strcmp(act, "play_pause") && companionOn() && companionMediaLaunch &&
                    (!mediaLive() || !media.player.length()) && (mediaTarget != "auto" || S.mediaLaunch != "none");
  if ((mediaLive() && media.appCtl) || launchPlay) {           // the desktop app talks to Spotify / Music / the browser directly
    evtMedia(act);
    if (!strcmp(act, "play_pause")) media.playing = !media.playing;
    return;
  }
  if (!consumerTap(key)) toast("Bilgisayara bağlı değil");   // media keys: whatever is playing on the computer
}

static void cyclePlayer() {
  static const char* order[4] = { "auto", "spotify", "music", "ytmusic" };
  int i = 0; for (int k = 0; k < 4; k++) if (mediaTarget == order[k]) i = k;
  mediaTarget = order[(i + 1) % 4];
  evtMedia("select");
  media.stamp = 0;                             // wait for the new player's info
  toast(mediaTarget == "auto" ? String("Oynatıcı: otomatik") : String(PLAYER_NAMES[i % 3]));
  dirty = true;
}

static void levelStep(bool vol, int steps) {
  int& v = vol ? sysSt.vol : sysSt.bright;
  if (sysLive() && v >= 0) {
    v = constrain(v + steps * (vol ? 2 : 5), 0, 100);
    sysLocalAt = millis();
    (vol ? volPending : brightPending) = true;
  } else {                                     // no desktop app (or value unknown): send keys
    for (int i = 0; i < abs(steps); i++) consumerTap(vol ? (steps > 0 ? CC_VOL_UP : CC_VOL_DOWN) : (steps > 0 ? CC_BRIGHT_UP : CC_BRIGHT_DOWN));
    keyFlash = steps > 0 ? 1 : -1; keyFlashWhat = vol ? 1 : 2; keyFlashAt = millis();
  }
  adjustAt = millis(); dirty = true;
}

static void toggleMic() {      // microphone mute needs the desktop app (no standard keyboard key for it)
  if (sysLive() && sysSt.mic >= 0) { sysSt.mic = sysSt.mic ? 0 : 1; sysLocalAt = millis(); evtSys("micMute", sysSt.mic); }
  else toast(companionOn() ? "Mikrofon bulunamadı" : "Mikrofon için masaüstü uygulaması gerekli");
  dirty = true;
}
static void toggleMute() {
  if (sysLive() && sysSt.vol >= 0) { sysSt.mute = !sysSt.mute; sysLocalAt = millis(); evtSys("mute", sysSt.mute); }
  else consumerTap(CC_MUTE);
  dirty = true;
}

static String musicPlayerForApp(const App& a) {
  String text = a.name + " " + a.launch.value + " " + a.launch.path + " " + a.launch.mac;
  text.replace("Ü", "ü"); text.replace("İ", "i"); text.toLowerCase();
  if (text.indexOf("spotify") >= 0) return "spotify";
  if (text.indexOf("youtube music") >= 0 || text.indexOf("music.youtube.com") >= 0) return "ytmusic";
  if (text.indexOf("apple music") >= 0 || text.indexOf("music.app") >= 0 || text.indexOf("müzik") >= 0 || text.indexOf("muzik") >= 0 || text.indexOf("itunes") >= 0) return "music";
  return "";
}

static void doLaunch(App* a) {
  if (!a) return;
  const Launch& L = a->launch;
  bool direct = L.method == M_RUN || L.method == M_SEARCH || ((L.method == M_TASKBAR) && (L.path.length() || L.mac.length()));
  // apps are opened only by the desktop app (system call); no Win+R / Start / Spotlight typing unless enabled
  if (direct && !companionOn() && !S.kbFallback) { toast("Game Deck uygulaması açık değil"); dirty = true; return; }
  if (activeLink() == L_NONE && !companionOn()) { toast("Bilgisayara bağlı değil"); dirty = true; return; }
  bool onApp = !items.empty() && items[sel].kind == K_APP && items[sel].app == a;
  if (onApp) {
    for (int i = 0; i <= 8; i++) { launchP = i / 8.0f; render(linkName()); delay(25); }
  } else { toast(a->name + " açılıyor"); render(linkName()); }
  bool ok;
  if (companionOn() && direct) { evtLaunch(a); ok = true; }   // desktop app opens it directly, no keystrokes
  else ok = runLaunch(a->launch, a->name);
  launchP = -1;
  if (!ok) toast("Bilgisayara bağlı değil");
  else if (S.mediaOn) {
    String player = musicPlayerForApp(*a);
    if (player.length()) {
      mediaTarget = player;                    // session pin, never change S.mediaPlayer / saved config
      media.stamp = 0; evtMedia("select");
      openPage(K_MEDIA);
    }
  }
  dirty = true;
}

/* ---------- Bağlantılar page ---------- */
static void connAct() {
  auto rows = connRows();
  if (connCur < 0 || connCur >= (int)rows.size()) return;
  const ConnRow& r = rows[connCur];
  if (r.type != CR_FORGET) connConfirmAt = 0;
  switch (r.type) {
    case CR_ALL: btSelectAll(); toast("Eşleşmiş bütün bilgisayarlar bağlanabilir"); connEdit = false; break;
    case CR_HOST: btSelect(r.a); toast(btName(r.a) + " seçildi"); connEdit = false; break;
    case CR_PAIR: btPairStart(); connEdit = false; break;
    case CR_FORGET:
      if (connConfirmAt && millis() - connConfirmAt < 4000) {
        connConfirmAt = 0; connCur = 0; connEdit = false;
        toast("Siliniyor…"); render(linkName());
        toast(bleForget() ? "Eşleşmeler silindi · bilgisayarlarda da kaldır" : "Silinemedi: cihazı yeniden başlatıp dene", 3500);
      }
      else connConfirmAt = millis() | 1;
      break;
  }
  dirty = true;
}
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
void loop() {
  protoPoll();
  if (configChangedFlag) { configChangedFlag = false; crumbSet("apply"); applySideEffects(); crumbClear(); }
  if (companionNew) { companionNew = false; toast("Masaüstü uygulaması bağlı"); dirty = true; evtMedia("select"); }
  if (mailNew) { mailNew = false; mailWake(); }
  if (mailActive() && !screenOff) mailInput();
  crumbSet("input"); handleInput(); crumbClear();
  connPoll();
  wifiPoll();
  if (wf.dirty) { wf.dirty = false; dirty = true; }   // Wi-Fi state (and a moved screen buffer) redraw the screen

  uint32_t now = millis();
  static uint32_t tBat = 0, tStatus = 0, tFrame = 0, tTheme = 0;
  if (now - tTheme >= 3000) { tTheme = now; bool light = effectiveLight(); if (light != lightTheme) { applyTheme(light); dirty = true; } }
  static Link lastLink = L_NONE;
  if (now - tBat > 2000) { tBat = now; uint8_t oldBat = batPct; bool oldCharge = charging; readBattery(); bleBattery(batPct); if (oldBat != batPct || oldCharge != charging) dirty = true; }
  if (now - tStatus > 5000) { tStatus = now; evtStatus(); if (!ecoActive) dirty = true; }
  Link l = activeLink(); if (l != lastLink) { lastLink = l; dirty = true; evtStatus(); }
  static uint8_t lastIcons = 0xFF; static uint32_t tIcons = 0;   // home BT / Wi-Fi icons (1.13.1), also in eco mode
  if (now - tIcons >= 500) { tIcons = now; uint8_t ic = btIconState() | wifiIconState() << 2; if (ic != lastIcons) { lastIcons = ic; if (!items.empty() && items[sel].home) dirty = true; } }

  bool onHome = !items.empty() && items[sel].home;
  bool onWidgets = curKind() == K_WIDGETS;
  if (statsDirty) { statsDirty = false; if (onHome || onWidgets) dirty = true; }

  // media / system pages: send level changes (throttled), leave adjust mode after a pause
  static uint32_t volSentAt = 0, brightSentAt = 0;
  if (volPending && now - volSentAt >= 60) { volPending = false; volSentAt = now; evtSys("vol", sysSt.vol); }
  if (brightPending && now - brightSentAt >= 200) { brightPending = false; brightSentAt = now; evtSys("bright", sysSt.bright); }
  if (adjust && now - adjustAt > 6000) { adjust = 0; dirty = true; }
  uint8_t kind = curKind();
  bool onPage = kind == K_MEDIA || kind == K_SYS;
  if (mediaDirty) { mediaDirty = false; if (onPage) dirty = true; }

  // idle handling
  uint32_t idle = (now - lastActivity) / 1000;
  if (S.homeOn && !(S.mediaStay && curKind() == K_MEDIA) && curKind() != K_WIDGETS && S.returnAfter > 0 && idle >= (uint32_t)S.returnAfter && sel != 0 && !items.empty() && items[0].home) { selectIndex(0); }
  // dimming / auto power-off: separate settings on cable (USB host or charger) and on battery, 0 = off
  bool onCable = extPower;
  int dimLimit = onCable ? S.dimAfterUsb : S.dimAfter, sleepLimit = onCable ? S.sleepAfterUsb : S.sleepAfter;
  int dimLevel = onCable ? S.dimLevelUsb : S.dimLevel;
  ecoAnimFps = min(S.animFps, onCable ? S.ecoFpsUsb : S.ecoFps);
  int ecoLimit = onCable ? S.ecoAfterUsb : S.ecoAfter;
  bool ecoBlocked = protoTransferBusy() || adjust || (toastUntil && now <= toastUntil) || mailActive();
  if (ecoActive && (ecoLimit <= 0 || adjust || (toastUntil && now <= toastUntil) || mailActive())) ecoSuspend();
  if (!ecoActive && !ecoBlocked && ecoLimit > 0 && idle >= (uint32_t)ecoLimit) ecoEnter();
  if (dimmed && dimLimit <= 0) { dimmed = false; setBright(S.brightness); }          // switched to a source with dimming off
  if (!screenOff && !dimmed && dimLimit > 0 && idle >= (uint32_t)dimLimit && !mailActive()) { dimmed = true; }
  if (!screenOff && dimmed) setBright(max(5, S.brightness * dimLevel / 100));
  if (sleepLimit > 0 && idle >= (uint32_t)sleepLimit && !mailActive()) goSleep();

  onHome = !items.empty() && items[sel].home;
  bool mailOn = mailActive();
  static bool mailWas = false;
  if (mailOn != mailWas) { mailWas = mailOn; dirty = true; }   // note shown or gone: redraw the whole screen
  bool animate = onHome && !screenOff && S.animKind != A_NONE && !mailOn;
  static int64_t clockMinute = -1;
  int64_t minute = st.timeAt ? (st.epoch + st.tz + (int64_t)((now - st.timeAt) / 1000)) / 60 : -1;
  bool clockChanged = minute != clockMinute; clockMinute = minute;
  static uint8_t liveBits = 0;
  uint8_t bits = (cpuFresh() ? 1 : 0) | (gpuFresh() ? 2 : 0) | (netFresh() ? 4 : 0) | (wxFresh() ? 8 : 0) | (fxFresh() ? 16 : 0) | (mediaLive() ? 32 : 0) | (sysLive() ? 64 : 0);
  if (bits != liveBits) { liveBits = bits; dirty = true; }
  bool toastExpired = toastUntil && now > toastUntil;
  if (toastExpired) { toastUntil = 0; dirty = true; }
  if (!screenOff) {
    if (dirty || (!ecoActive && ((animate && now - tFrame >= 40) || (onPage && now - tFrame >= 250) || ((onHome || onWidgets) && now - tFrame >= 1000) || (mailOn && now - tFrame >= 250)))) {
      tFrame = now; dirty = false; crumbSet("render"); render(linkName()); crumbClear();
    } else if (ecoActive) {
      if (animate && ecoAnimFps > 0 && now - tFrame >= (uint32_t)(1000 / ecoAnimFps)) { tFrame = now; renderEcoAnim(now); }
      if (clockChanged) renderEcoClock();
    }
  }
  delay(2);
}

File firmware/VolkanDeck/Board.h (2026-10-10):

#pragma once
// LilyGO T-Display-S3 + KY-040 + 2 buttons
#define FW_VERSION "1.15.1"
#include "esp_heap_caps.h"

// PSRAM (1.12.1): without BOARD_HAS_PSRAM Arduino 3.x compiles its PSRAM layer out and the 8 MB is never used.
#ifndef BOARD_HAS_PSRAM
#error "Derleme tools/build_firmware.sh ile yapılmalı (BOARD_HAS_PSRAM yok)"
#endif
// psramFound() is not enough: with CONFIG_SPIRAM_BOOT_INIT Arduino reports true even when startup failed.
static inline bool psramOk() { return heap_caps_get_total_size(MALLOC_CAP_SPIRAM) > 0; }
static inline uint32_t psramKB() { return (uint32_t)(heap_caps_get_total_size(MALLOC_CAP_SPIRAM) / 1024); }

// CPU scaling (240 <-> 80 MHz) is off since 1.8.1: the switch back to 240 MHz happened right before the
// config write and the board restarted ("Cihaza yaz" on Windows). Idle redraw saving stays enabled.
#ifndef VOLKAN_ECO_CPU
#define VOLKAN_ECO_CPU 0
#endif

#define PIN_LCD_POWER 15
#define PIN_LCD_BL    38
#define PIN_BAT       4
#define BAT_MAH       2000     // Efcell 2000 mAh Li-Po
#define BAT_CHARGE_MA 500      // TP4065, R_PROG (R13) 2 kOhm -> 1000 V / 2 kOhm = 0.5 A (LilyGO: 500 mA)
#define BAT_STEP_V    0.06f    // voltage step that marks a charger plugged in / pulled out
#define BAT_IR_V      0.10f    // voltage lift while charging (charge current x cell/wiring resistance)

#define PIN_ENC_CLK   1
#define PIN_ENC_DT    2
#define PIN_ENC_SW    10
#define PIN_BTN_A     11
#define PIN_BTN_B     12
#define PIN_KEY_PWR   0    // board BOOT key: power (swapped in 1.1.1)
#define PIN_KEY_RST   14   // board key: restart (swapped in 1.1.1)

#include <LovyanGFX.hpp>

class LGFX : public lgfx::LGFX_Device {
  lgfx::Panel_ST7789  _panel;
  lgfx::Bus_Parallel8 _bus;
  lgfx::Light_PWM     _light;
public:
  LGFX() {
    { auto c = _bus.config();
      c.freq_write = 20000000;
      c.pin_wr = 8; c.pin_rd = 9; c.pin_rs = 7;
      c.pin_d0 = 39; c.pin_d1 = 40; c.pin_d2 = 41; c.pin_d3 = 42;
      c.pin_d4 = 45; c.pin_d5 = 46; c.pin_d6 = 47; c.pin_d7 = 48;
      _bus.config(c); _panel.setBus(&_bus); }
    { auto c = _panel.config();
      c.pin_cs = 6; c.pin_rst = 5; c.pin_busy = -1;
      c.panel_width = 170; c.panel_height = 320;
      c.offset_x = 35; c.offset_y = 0; c.offset_rotation = 0;
      c.readable = false; c.invert = true; c.rgb_order = false;
      c.dlen_16bit = false; c.bus_shared = false;
      _panel.config(c); }
    { auto c = _light.config();
      c.pin_bl = PIN_LCD_BL; c.invert = false; c.freq = 22000; c.pwm_channel = 7;
      _light.config(c); _panel.setLight(&_light); }
    setPanel(&_panel);
  }
};

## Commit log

2026-10-05 Volkan Deck: firmware v1.2.1, masaüstü uygulaması, ayar sayfası, kasa v4
    - firmware/: ESP32-S3 (T-Display-S3) kaynak + derlenmiş bin'ler (v1.2.1, kalıcı GIF)
    - web/: ayar sayfası kaynağı ve derlenmiş StreamDeck-Ayar.html (firmware gömülü,
    yükleme sonrası otomatik yeniden başlatma)
    - app/: Electron masaüstü uygulaması (Windows + macOS, doğrudan uygulama açma,
    tepsi / menü çubuğu modu)
    - installer/: Windows ve macOS kurulum betikleri
    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
    [VolkanDeck_kasa_v4.3mf, partitions.csv, v4_arka_kapak.stl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]
2026-10-05 Kasa: arka kapak v5 (v4 gövdeye takılır, kırılmayan tutturma)
    v4 kapağın tırnaklarında kanca kökün dibindeydi (~%4 esneme, katmanlara dik) ve
    PLA'da kırılıyordu. v5: altta 2 sabit dil, üstte kapak düzleminde esneyen 2 yaylı
    kol (~%0,7), 0,8 mm dış çerçeve, 0,35 mm boşluk. Gövde değişmedi.
    Claude-Session: https://claude.ai/code/session_01FWFAaNUZNF2xMFhUC5aX99
    [v5_arka_kapak.stl]
2026-10-05 Firmware 1.5.0: koyu / açık / otomatik tema, güç tuşuyla gerçek kapanma, medya sayfasında kalma
    - Ekran teması (Cihaz ayarları): koyu (tam siyah zemin), açık (kasaya uyan sıcak beyaz) veya
    otomatik (saate göre, varsayılan 07:00–19:00 açık). Renkli zeminlerde yazı rengi parlaklığa göre seçilir;
    ayar sayfasındaki simülatör aynı temayı gösterir.
    - Güç tuşunu 2 sn basılı tutunca cihaz kapalı kalıyor: uykuda GPIO0 RTC pull-up ile sabit, BLE/USB/zamanlayıcı
    uyandırması kapalı; tuş dışı bir sebeple (USB reset vb.) açılırsa ekranı yakmadan yeniden uyur.
    - Medya sayfasındayken boşta ana sayfaya dönmeme ayarı (pages.media.stay, varsayılan aç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
    [Board.h, Store.h, Ui.h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]
2026-10-05 Firmware 1.5.1: karartma ve otomatik kapanma kabloda / pilde ayrı
    - Cihaz ayarlarında iki grup: "Kabloyla bağlıyken (USB / şarj)" ve "Pille
    çalışırken"; her birinde Ekranı karart ve Otomatik kapan, 0 = kapalı
    - Yeni alanlar device.dimAfterUsb / sleepAfterUsb; dimAfter / sleepAfter pil
    için kalır. Eski config'te kablo = eski karartma süresi, kapanma kapalı
    - Kablo: USB'ye bağlı ya da şarj oluyor. Karartma kapalı bir kaynağa
    geçilince karartılmış ekran aydınlanır
    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
2026-10-06 Belgeler: 1.6.1'de yanlışlıkla boşalan README geri getirildi
2026-10-06 Firmware 1.7.0: açık ve koyu tema için ayrı animasyon
    Bulut ajanının claude/upbeat-pasteur-yhkjnp dalındaki 7afc224 commit'i;
    orada derlenemeyen firmware 1.7.0 burada derlenip ayar sayfasına gömüldü.
    - Kart iki animasyon saklar: koyu tema /anim.bin, açık tema /anim_light.bin; biri yoksa diğeri oynar
    - Protokol: anim_begin "slot":"light", anim_clear, hello yanıtında anim / animLight
    - Ayarlar: Kendi GIF'im altında Koyu / Açık tema sekmeleri
2026-10-06 Firmware 1.8.0: Outlook'a yeni posta gelince cihazda bildirim
    macOS 27'de lsappinfo -long ile okunuyor; firmware 1.8.0 derlenip ayar sayfasına gömüldü.
2026-10-06 Uygulama: komut dosyaları (.bat, .ps1, .sh, .command…) uygulama gibi eklenebilir
    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
2026-10-07 Kasa: v6 ekran tutucu, tırnaklar yerine direk, baskı çubuğu ve filament pim
    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
    [VolkanDeck_kasa_v6.3mf, v6_baski_cubugu_sag.stl, v6_baski_cubugu_sol.stl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]
2026-10-07 Kasa: v6 düz dikdörtgen USB-C girişi ve 15 mm ped yuvaları
    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
    [VolkanDeck_kasa_v6.3mf, v6_govde.stl]
2026-10-07 Kasa: v6 2 cm ped yuvaları ve basılabilir kilit pimleri
    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
    [VolkanDeck_kasa_v6.3mf, v6_govde.stl, v6_pim.stl]
2026-10-07 Kasa: v6 ayak yuvaları 15 mm pedlere göre
    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
    [VolkanDeck_kasa_v6.3mf, v6_govde.stl]
2026-10-07 Kasa: v6 döndürgeç düğmesi Ø24, tırtıllı ve çanak üstlü
    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
    [VolkanDeck_kasa_v6.3mf, v6_dugme.stl]
2026-10-07 Belgeler: kart şarj akımı (TP4065, 500 mA)
    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
2026-10-07 Firmware 1.9.4: sayfalar Menü'de, uygulama listesine web sitesi kısayolu
    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
2026-10-08 Firmware 1.12.1: ek bellek (8 MB PSRAM) gerçekten açıldı
    Kart tanımında BOARD_HAS_PSRAM yoktu; Arduino 3.x PSRAM katmanını derlemiyordu
    (psramFound/ps_malloc boş). Derleme bayrağı ve bayraklara göre ayrılan çekirdek
    önbelleği eklendi. 1.12.0'ın QSPI derlemesi kaldırıldı; ikon önbelleği ve Bellek
    kartı korundu.
2026-10-08 Firmware 1.13.6: Wi-Fi taraması kartı dondurmuyor
    Tarama arka planda; ayar sayfası Wi-Fi bağlıyken açılışta taramaz.
    Wifi.h → WifiLink.h (Mac'te temiz derlemede <WiFi.h> ile karışıyordu).
2026-10-22 Bluetooth: deck sonradan açılınca kendiliğinden bağlanır; uzaktan açmada Türkçe karakterler düzeldi
    - wol-setup.ps1 BOM ile (Windows PowerShell 5.1 BOM'suz betiği ANSI okuyordu: "ayarlarÄ±"); sonuç satır sonları korunur
    - Tarama cihazı görmediyse geri çekilme büyümez, 20 sn'de bir denenir; pencere öne gelince ve uykudan dönünce hemen
    - Windows eşleşme kontrolü Game Deck servis düğümüne de bakar (eski adla eşleşmiş cihaz)
    - Cihaz 60 sn bağlı değilken ölçüm, medya ve Outlook yardımcıları durur
    - Açılışta ağ yoksa güncelleme kontrolü 5 dk arayla 3 kez yeniden denenir
    - Üst sekmelerdeki gereksiz kaydırma çubuğu kaldırıldı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
